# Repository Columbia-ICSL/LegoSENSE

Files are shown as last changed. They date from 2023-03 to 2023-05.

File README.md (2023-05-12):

# LegoSENSE
LegoSENSE makes building and deploying sensing systems as easy and as fast as building legos, for **everyone**. LegoSENSE is a software & hardware framework for rapid sensor deployments.

We have provided detailed documentation (and instructional videos soon), for both users, and developers looking to expand the ecosystem.

## Getting Started

For general users, if your system did not come with the software, please flash our prebuilt Raspberry Pi image to the SD card and plug in the hardware.

To develop or build the system from source, please clone this repository using the following git commands. Make sure to pass the `--recurse-submodules` flag to the clone command.

```bash
git clone --recurse-submodules git@github.com:Columbia-ICSL/LegoSENSE.git
```

`/software` contains the source code for LegoSENSE's software system running on Raspberry Pi.

`/hardware` contains all the design resources for developing hardware modules for LegoSENSE, including instructions, hardware references, and design templates.

## Citation

If your academic work has used LegoSENSE, please cite our paper below.

> Minghui Zhao, Stephen Xia, Jingping Nie, Kaiyuan Hou, Avik Dhupar, and Xiaofan Jiang. 2023. LegoSENSE: An Open and Modular Sensing Platform for Rapidly-Deployable IoT Applications. In International Conference on Internet-of-Things Design and Implementation (IoTDI '23), May 09--12, 2023, San Antonio, TX, USA. ACM, New York, NY, USA 14 Pages. [https://doi.org/10.1145/3576842.3582369](https://doi.org/10.1145/3576842.3582369)

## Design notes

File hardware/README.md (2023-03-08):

# LegoSENSE Development Guide - Hardware
*This document is written for a hardware developer audience. For information on using LegoSENSE, see [Getting Started](../README.md).*

## Getting Started: hardware design steps

### Step 1: Get Sensor to Work on Breadboard

Acquire a sensor evaluation board (breakout board) and make it work with Raspberry Pi. You may consult the sensor manufacturer for example codes and getting started guides. Once you have the sensor's driver code running on Raspberry Pi and are able to acquire data, you are ready for the next step.

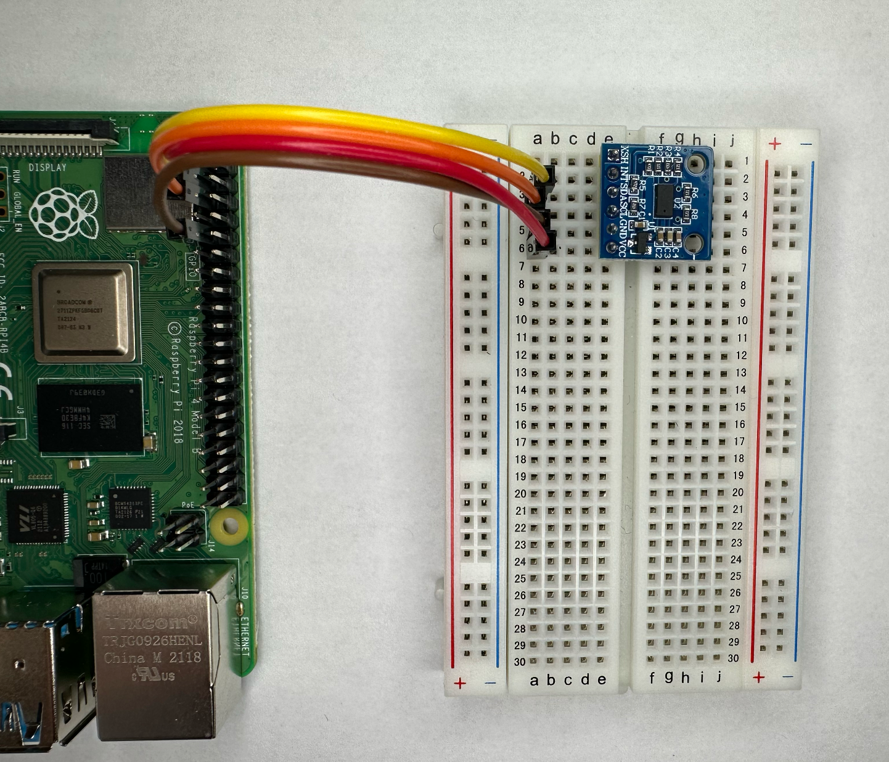
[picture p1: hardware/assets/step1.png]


### Step 2: Switch to Module Development Board

In this step, you will move the sensor circuit to a module-like development board that can be plugged into LegoSENSE's carrier board.

There are three module development boards you can use as shown below. On the top half of the board, the 21-Pin connector is broken out for soldering; on the bottom half of the board, type 1 employs a breadboard-style layout, type 2 employs a protoboard-style layout and type 3 includes the common 1.25mm JST connector and 1.0mm I2C connector (STEMMA QT / Qwiic).

| Development Board Type 1 | Development Board Type 2 | Development Board Type 3 |
| --- | --- | --- |
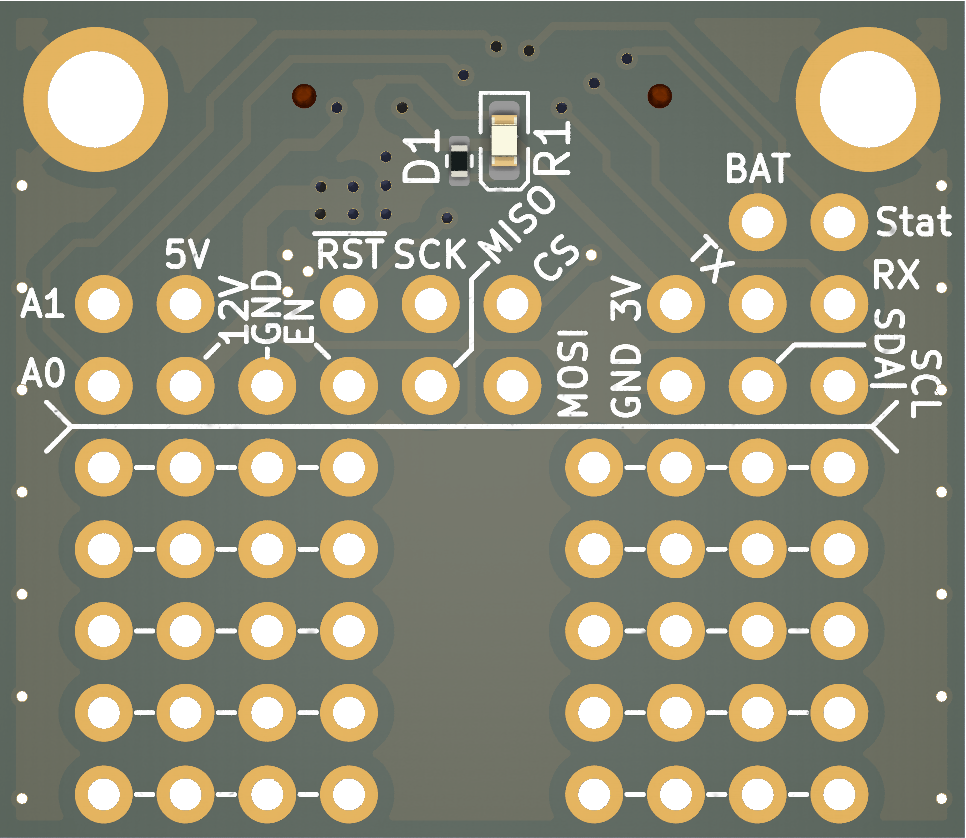
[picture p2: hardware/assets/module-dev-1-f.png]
module-dev-1-f
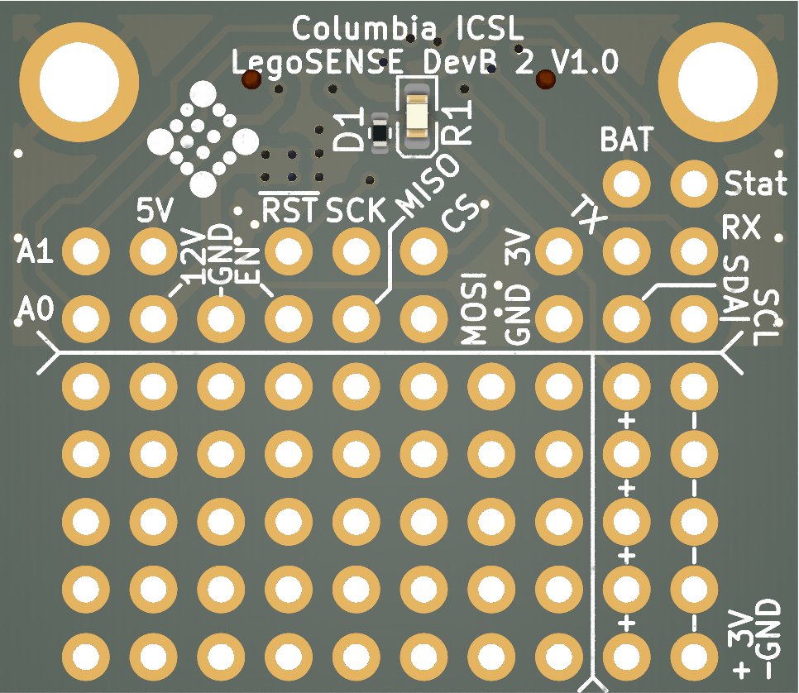
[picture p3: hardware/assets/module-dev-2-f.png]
module-dev-2-f
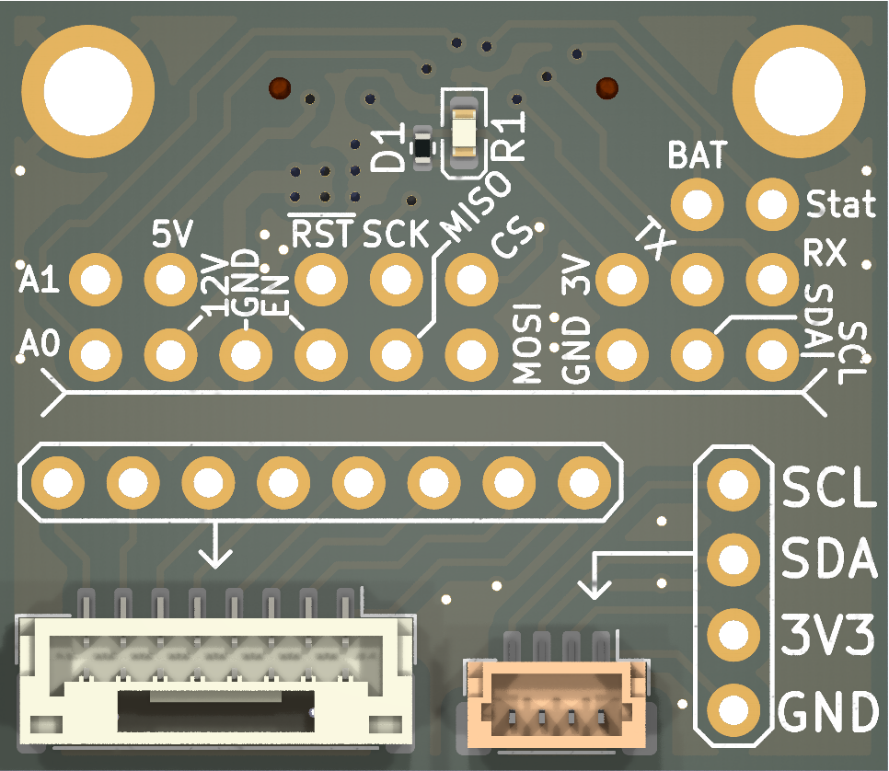
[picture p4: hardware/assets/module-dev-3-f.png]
module-dev-3-f
|  |  |  |
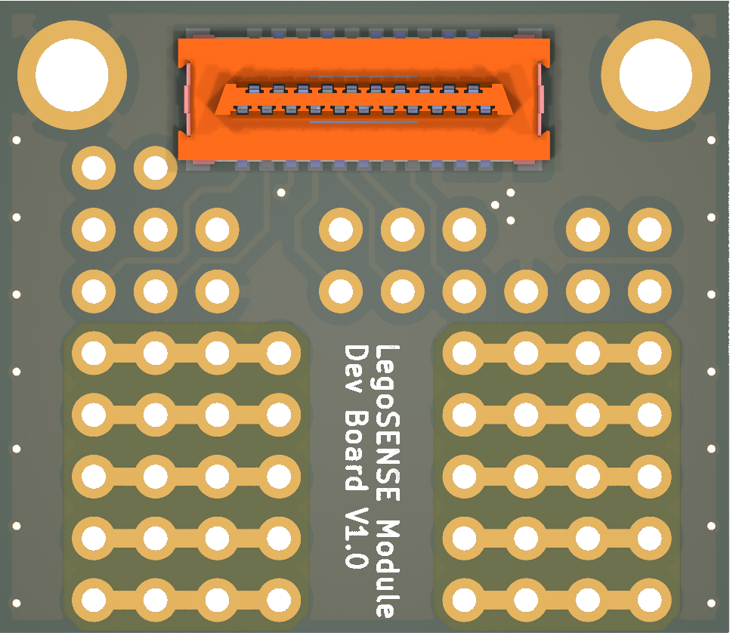
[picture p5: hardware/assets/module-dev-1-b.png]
module-dev-1-b
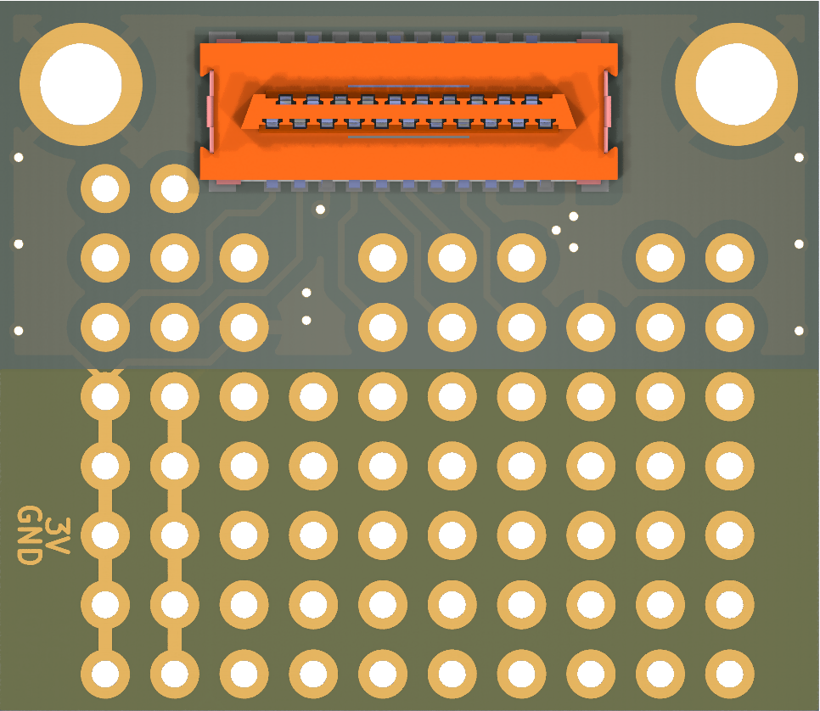
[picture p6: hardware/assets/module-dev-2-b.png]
module-dev-2-b
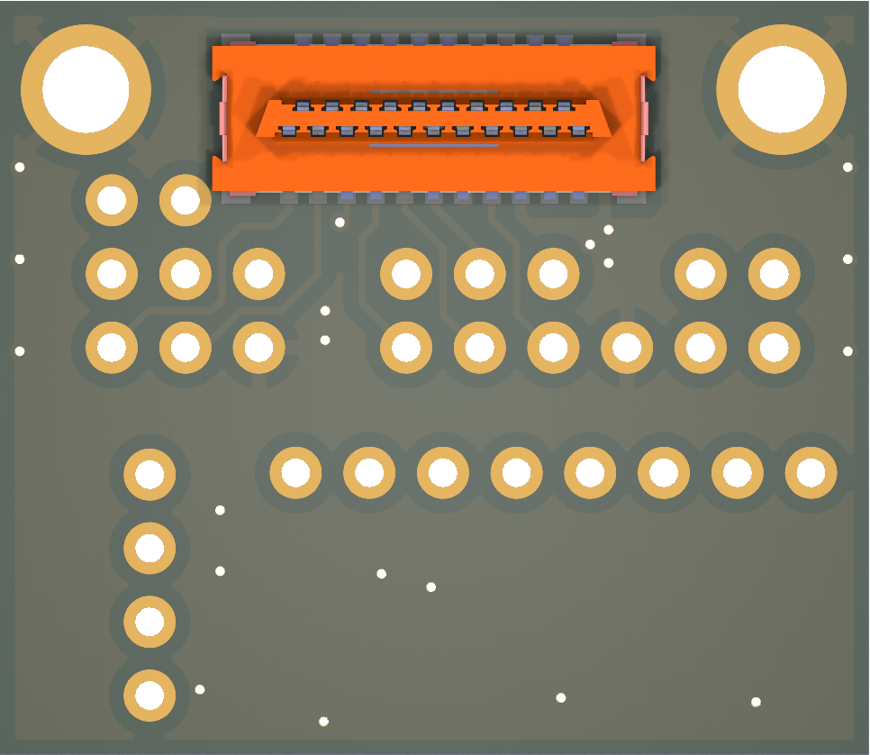
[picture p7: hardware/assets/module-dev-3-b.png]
module-dev-3-b
|  |  |  |

Choose the one that's most convenient for you to work with, and move the circuit from breadboard to the development board and solder it on there.

Plug the evaluation board into carrier board. Depending on which slot you've plugged in, you will need to change the pin definitions in your sensor driver code to match the pin that the specific carrier board module slot uses. You can consult the table under [Carrier Board Bus Layout](#carrier-board-bus-layout).

Once you get the sensor driver code up running, you are ready for the next step.

### Step 3: Port code into LegoSENSE Framework

In this step, we will port the working sensor driver code into LegoSENSE's framework. Follow [Software Development Guide](../software_dev.md) - once you have the sensor driver running from LegoSENSE's software stack and see the sensor data on the dashboard, you are ready for the final step.

### Step 4: Design and Manufacture Module PCB

In this step, we will create the final version of the sensor module PCB. A template sensor module PCB project is provided in `/hardware/sensor-modules/template`.

| Template Sensor Module PCB (front) | Template Sensor Module PCB (back) |
| --- | --- |
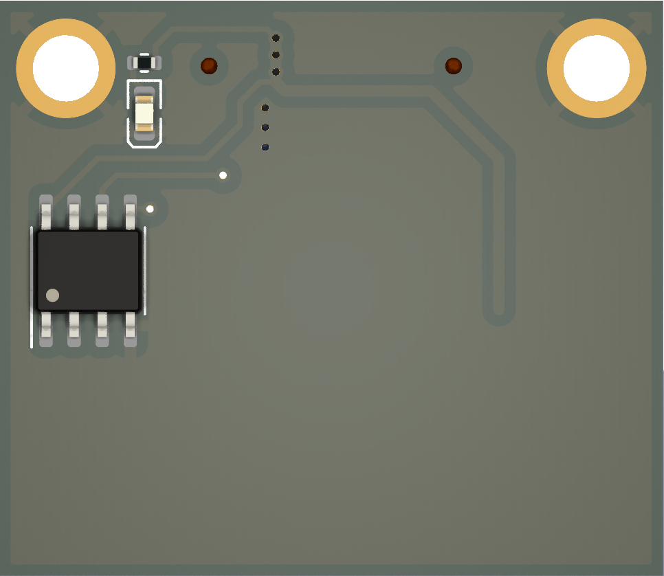
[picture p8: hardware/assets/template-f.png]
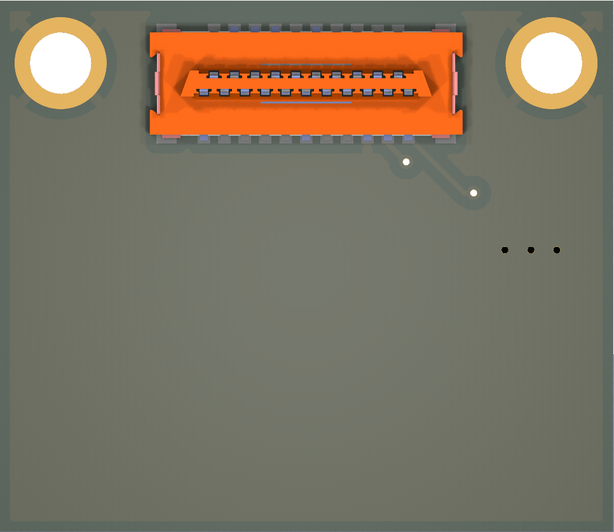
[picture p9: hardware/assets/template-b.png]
|  |  |

1. Duplicating the module template PCB file. This template file is pre-populated with the LegoSENSE standard 21-Pin connector and a EEPROM for auto-recognition of the module. Do not edit this part.
2. Move all the sensor components and peripherials onto the bottom part of the module PCB.
3. Finish the PCB and manufacture it. You could either program the eeprom at manufacturing time and populate it with the ascii string name of the driver, or you can plug in the PCB and use `/software/src/hal/eeprom/write_eep.py` to program the eeprom.

## Project Layout

- `sensor-modules`
  - `template`
  - `<existing_module_names>`
    - `<module_name>.kicad_pro/kicad_sch/kicad_pcb`: KiCad project for the sensor module PCB
    - `jlcpcb`: Folder containing PCB fabrication files. This folder is generated by KiCad plugin [kicad-jlcpcb-tools]( https://github.com/bouni/kicad-jlcpcb-tools).
      - `gerber`: Gerber file for PCB manufacturing
      - `assembly`: Bill of materials (BOM) and parts placement position file for pick-and-place machine (POS)

- `carrier-board`: Carrier board (as a Raspberry Pi shield) PCB design and fabrication files
  - `carrier-board.kicad_pro/kicad_sch/kicad_pcb`: KiCad project for the top-level carrier board PCB
  - `<ADC/eeprom_mux/HeaderToRpi4_overlay1/level_shifter_2ch/sensor_module>.kicad_sch`: Schematics files for submodules in the carrier board PCB project
  - `jlcpcb`: Folder containing PCB fabrication files. This folder is generated by KiCad plugin [kicad-jlcpcb-tools]( https://github.com/bouni/kicad-jlcpcb-tools).
    - `gerber`: Gerber file for PCB manufacturing
    - `assembly`: Bill of materials (BOM) and parts placement position file for pick-and-place machine (POS)
- `module-development-boards`: PCB designs for three different module development boards
- `kicad-library`: Submodule linked to a separate GitHub repository containing the PCB library symbols of the components used in the hardware designs.

### Current List of PCB Design Files

#### Carrier Board PCB

| Carrier Board Front Side | Carrier Board Back Side |
| --- | --- |
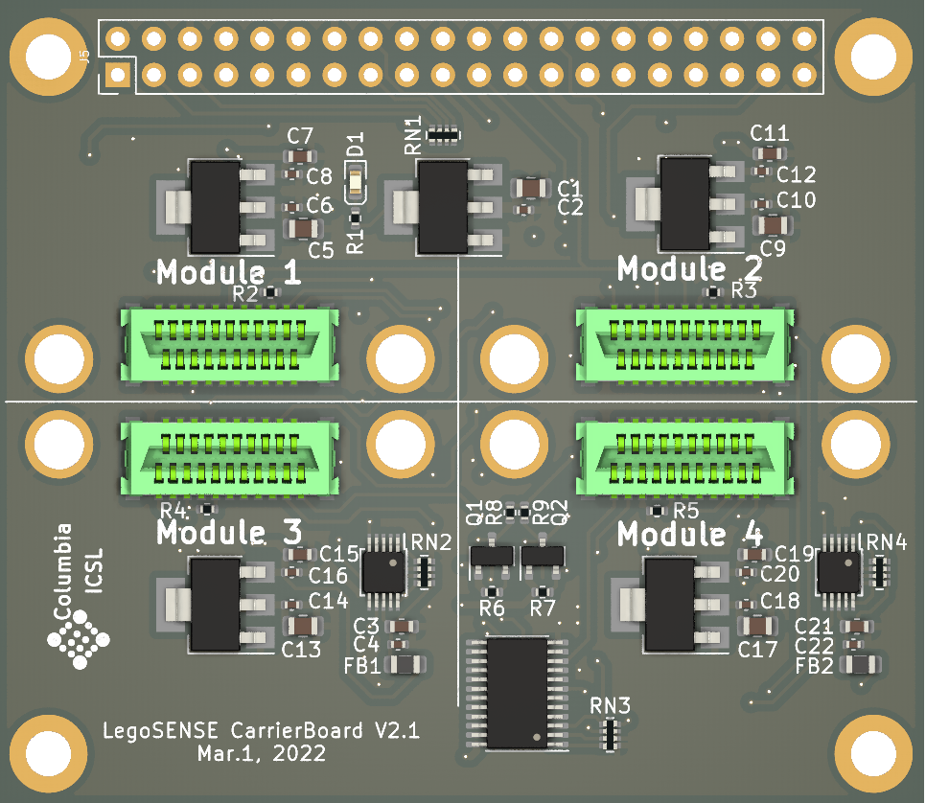
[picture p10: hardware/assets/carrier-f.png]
carrier-f
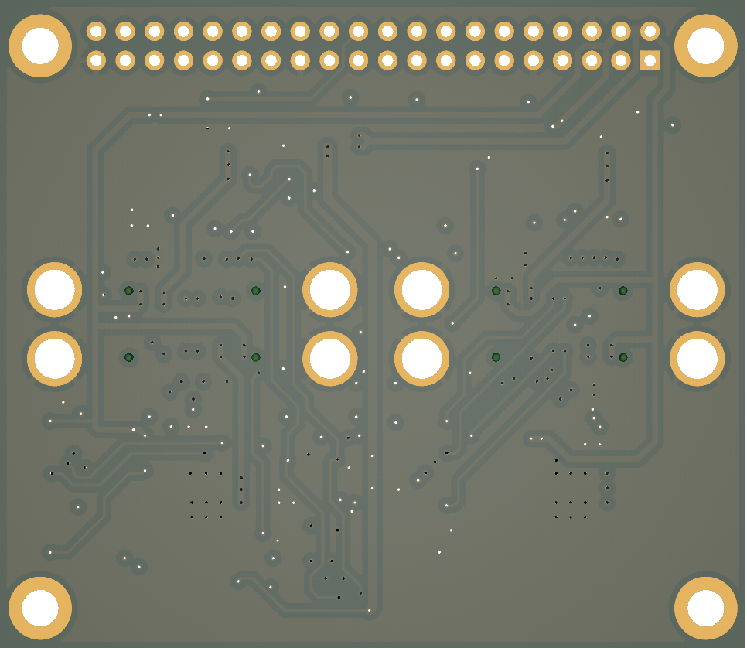
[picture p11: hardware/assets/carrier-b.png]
carrier-b
|  |  |

#### Sensor Modules

| **M1: Temperature, Humidity, Pressure, Wind Speed** | **M2: Ambient Light Color, Light Intensity** | **M3: Proximity, Microphone** | **M4: Motion (IMU)** |
| --- | --- | --- | --- |
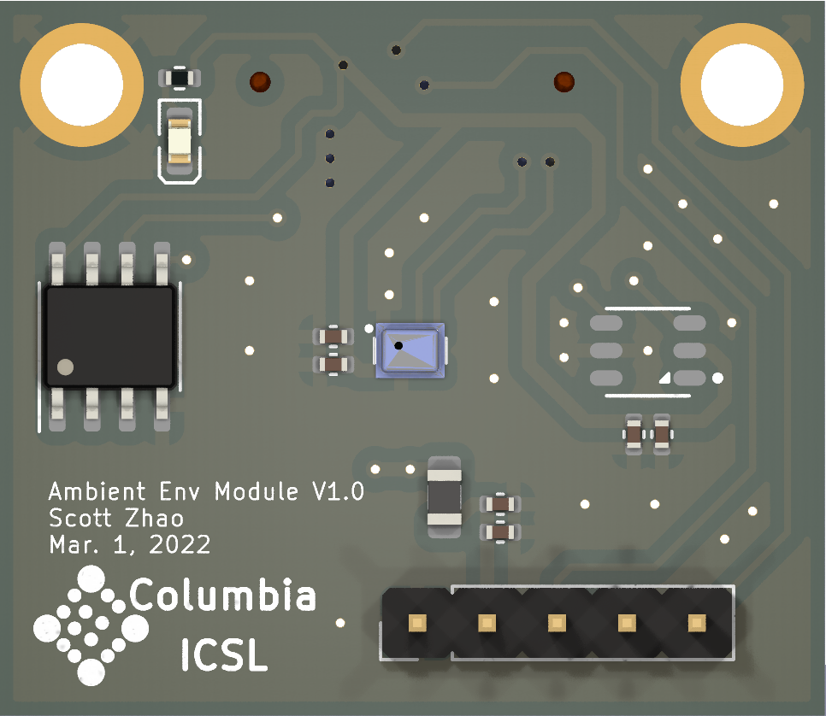
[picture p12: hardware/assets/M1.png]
M1
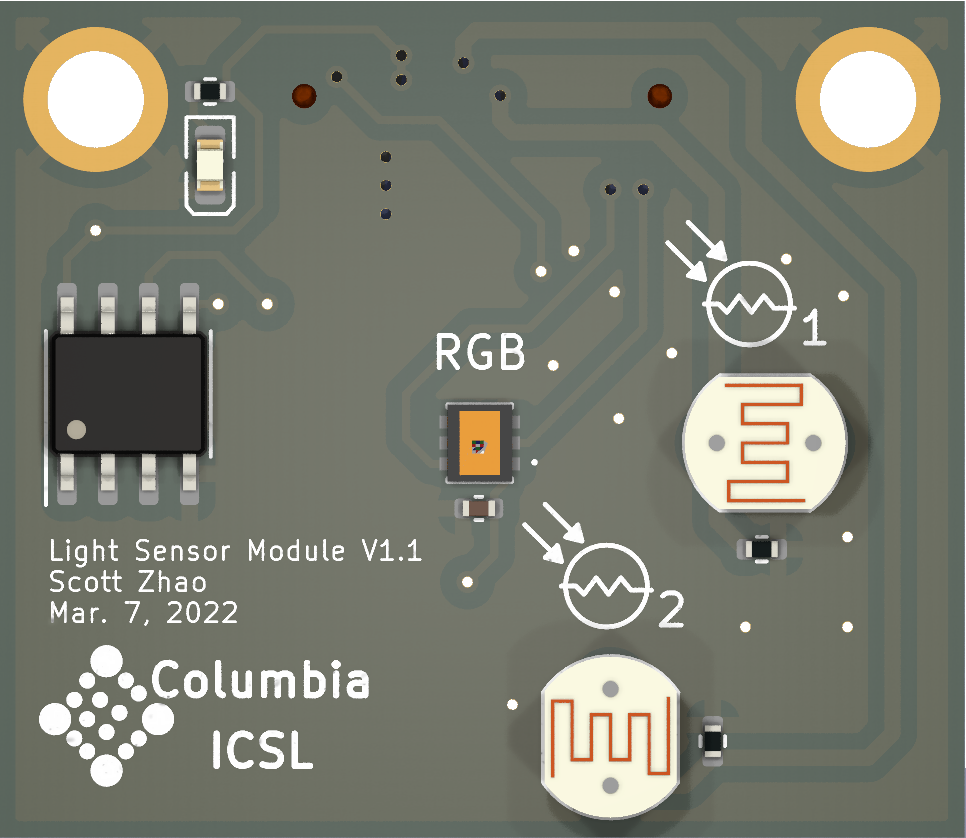
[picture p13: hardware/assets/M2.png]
M2
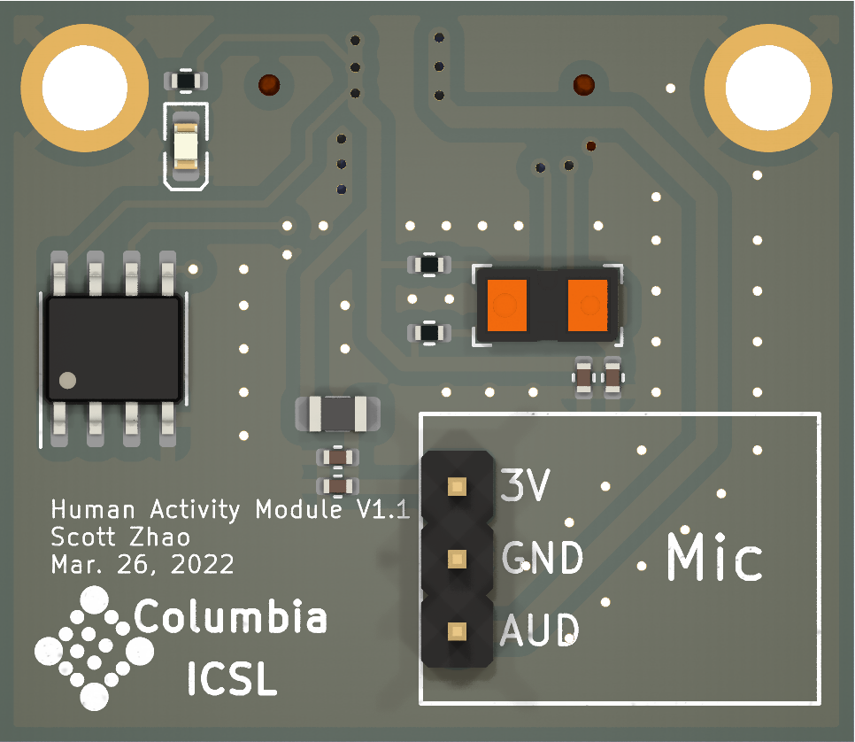
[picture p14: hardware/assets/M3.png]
M3
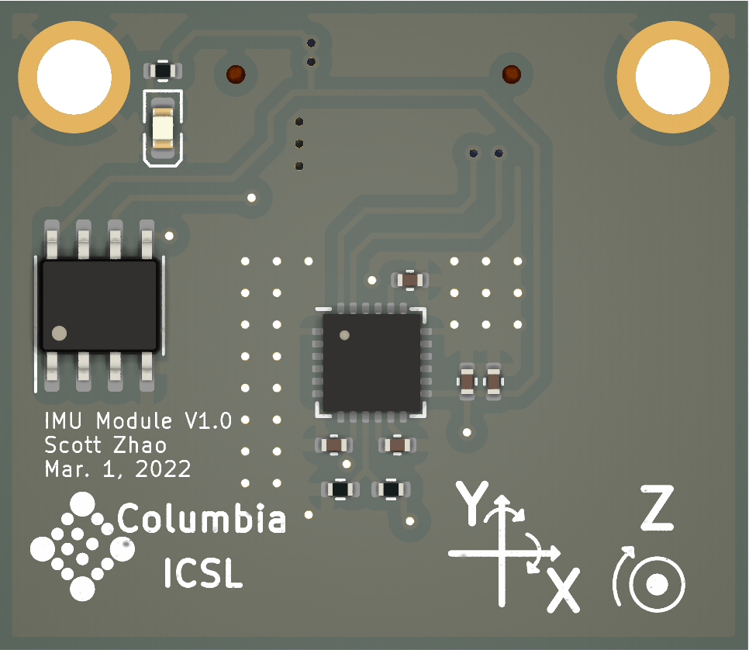
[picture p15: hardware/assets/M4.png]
M4
|  |  |  |  |
| **M5: Thermocouple (Temperature)** | **M6: Particulate Matter (PM1, PM2.5, PM10); Any I2C Sensor with STEMMA QT / Qwiic** | **M7: CO2, Volatile Organic Compound** | **M8: Gas Density (MQ-X Series)** |
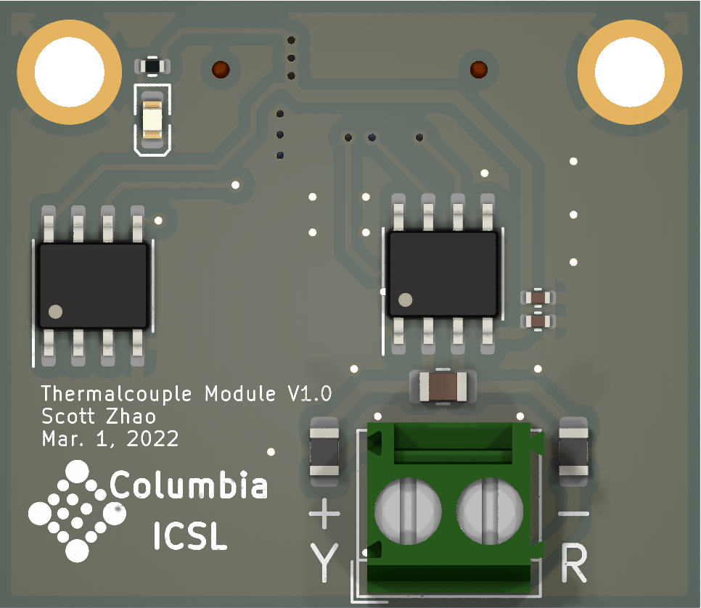
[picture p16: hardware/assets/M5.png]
M5
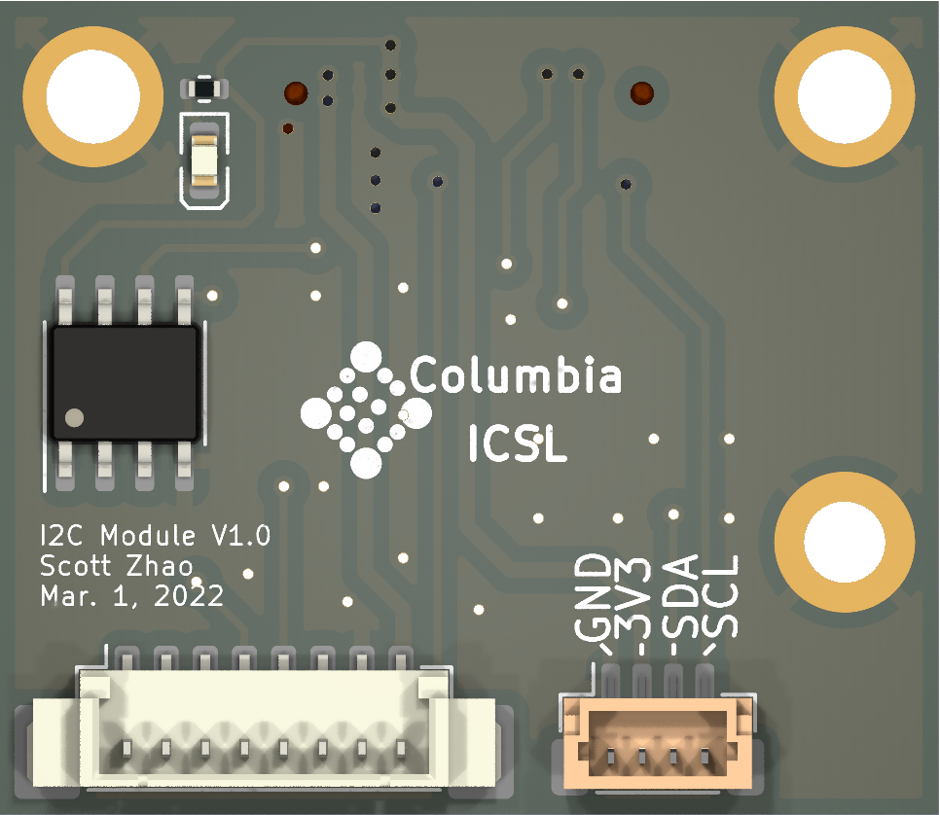
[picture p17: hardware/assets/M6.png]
M6
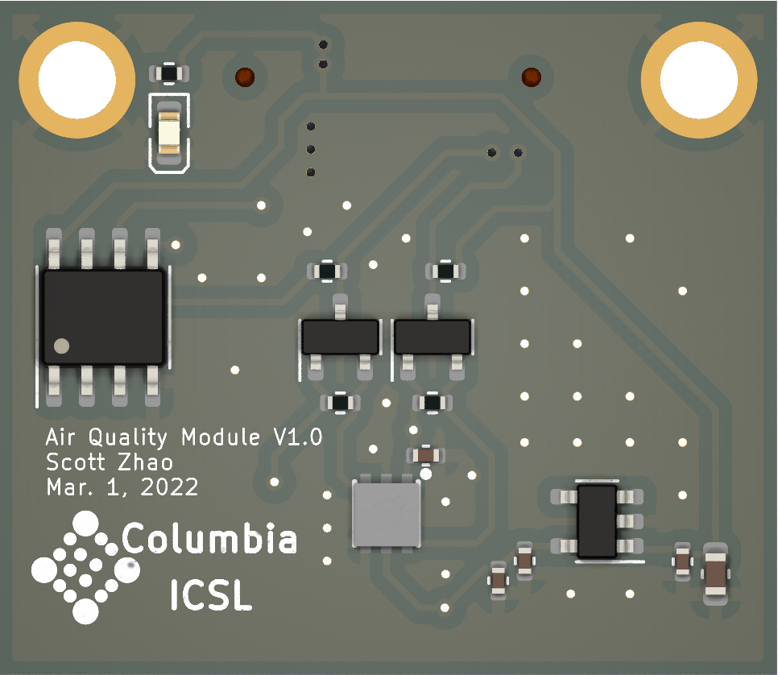
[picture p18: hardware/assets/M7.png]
M7
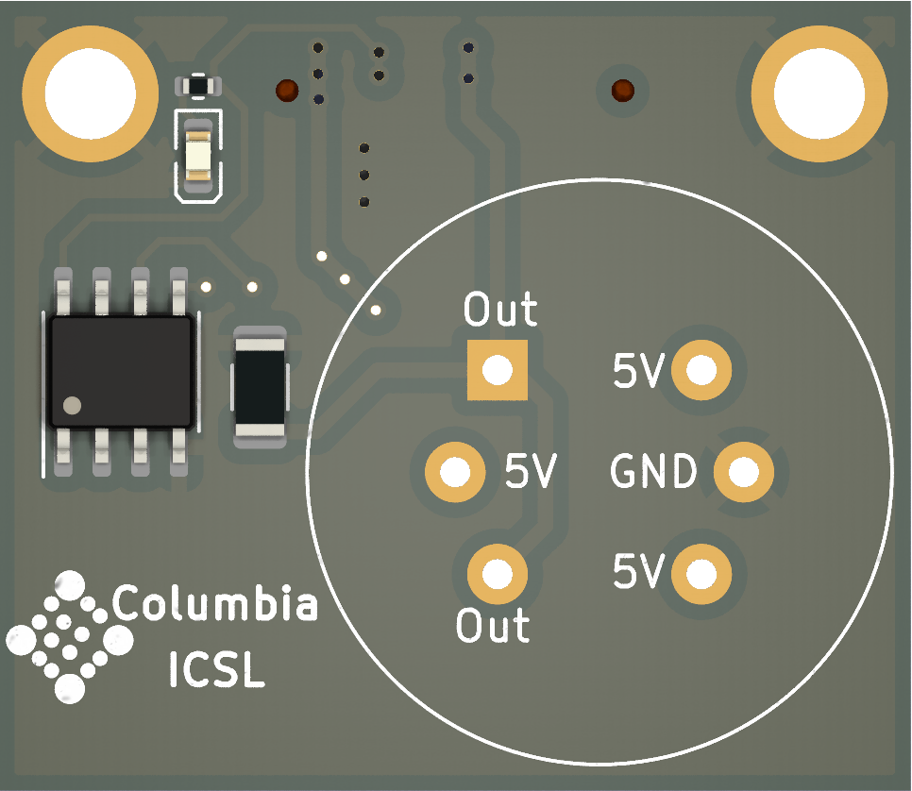
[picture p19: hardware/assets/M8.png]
M8
|  |  |  |  |

## Carrier Board Bus Layout
Note: Raspberry Pi GPIO numbering in this table are BCM (broadcom) pin numbers and is not the physical pin on Raspberry Pi board.

| | I2C | SPI | UART (TX, RX) | ADC | GPIO |
| --- | --- | --- | --- | --- | ---- |
| Module 1 | I2C1 <br/>`/dev/i2c-1` | SPI0, CS0 <br/>`/dev/spidev0.0` | UART1 (14, 15) <br/>`/dev/ttyS0` | ADC1, CH1-2 | 24 |
| Module 2 | I2C1 <br/>`/dev/i2c-1` | SPI0, CS1 <br/>`/dev/spidev0.1` | UART2 (0, 1) <br/>`/dev/ttyAMA1` | ADC1, CH3-4 | 25 |
| Module 3 | I2C6 <br/>`/dev/i2c-6` | SPI1, CS0 <br/>`/dev/spidev1.0` | UART3 (4, 5) <br/>`/dev/ttyAMA2` | ADC2, CH1-2 | 26 |
| Module 4 | I2C6 <br/>`/dev/i2c-6` | SPI1, CS1 <br/>`/dev/spidev1.1` | UART5 (12, 13) <br/>`/dev/ttyAMA3` | ADC2, CH3-4 | 27 |
| ADC1 | I2C1, addr=48 | | | | |
| ADC2 | I2C1, addr=49 | | | | |
| EEPROM MUX | I2C1, addr=70 | | | | |

### Raspberry Pi 4 Device Tree Overlay
```
[spi]
gpio=16,17,18,19,20,21=a4
dtoverlay=spi1-3cs
gpio=7,8,9,10,11=a0
dtoverlay=spi0-2cs

[I2C]
dtoverlay=i2c6

[UART]
enable_uart=1
dtoverlay=uart2
dtoverlay=uart3
dtoverlay=uart5
```

### Raspberry Pi 40-Pin Assignments
| Function | RPi PCB <br/>Pin# (BCM) | RPi PCB <br/>Pin# (BCM) | Function  |
| --- | --- | --- | --- |
| 3V3 | **1** (3V3) | **2** (5V) | 5V |
| I2C1_SDA | **3** (GPIO 2) | **4** (5V) | 5V |
| I2C1_SCL | **5** (GPIO 3) | **6** (GND) | GND |
| UART3_TX | **7** (GPIO 4) | **8** (GPIO 14) | UART0_TX  |
| GND | **9** (GND) | **10** (GPIO 15) | UART0_RX  |
| SPI1_CE1 | **11** (GPIO 17) | **12** (GPIO 18) | SPI1_CE0  |
| GPIO_M4 | **13** (GPIO 27) | **14** (GND) | GND |
| I2C6_SDA | **15** (GPIO 22) | **16** (GPIO 23) | I2C6_SCL  |
| 3V3 | **17** (3V3) | **18** (GPIO 24) | GPIO_M1 |
| SPI0_MOSI  | **19** (GPIO 10) | **20** (GND) | GND |
| SPI0_MISO  | **21** (GPIO 9) | **22** (GPIO 25) | GPIO_M2 |
| SPI0_SCK | **23** (GPIO 11) | **24** (GPIO 8) | SPI0_CE0  |
| GND | **25** (GND) | **26** (GPIO 7) | SPI0_CE1  |
| UART2_TX | **27** (GPIO 0) | **28** (GPIO 1) | UART2_RX  |
| UART3_RX | **29** (GPIO 5) | **30** (GND) | GND |
| *Not Used* | **31** (GPIO 6) | **32** (GPIO 12) | UART5_TX  |
| UART5_RX | **33** (GPIO 13) | **34** (GND) | GND |
| SPI1_MISO  | **35** (GPIO 19) | **36** (GPIO 16) | SPI1_CE2  |
| GPIO_M3 | **37** (GPIO 26) | **38** (GPIO 20) | SPI1_MOSI |
| GND | **39** (GND) | **40** (GPIO 21) | SPI1_SCK  |

## Module Connector
The universal connector used for all modules and carrier boards is a pair of 21 Pin Mezzanine Connectors shown below.

| Adapter Board Side<br/>21 Pin Mezzanine Connector Receipt | 21 Pin Mezzanine Connector Plug <br/>Sensor Module Side |
| --- | --- |
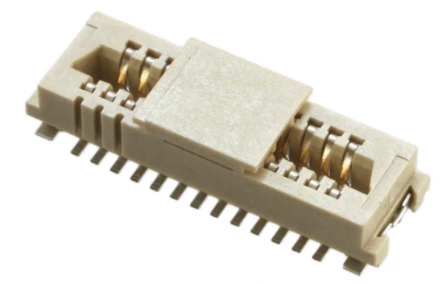
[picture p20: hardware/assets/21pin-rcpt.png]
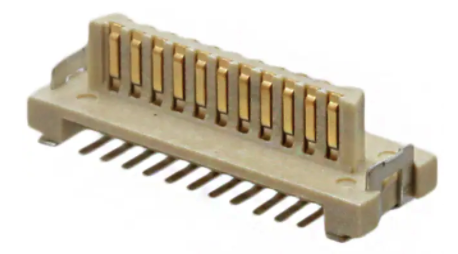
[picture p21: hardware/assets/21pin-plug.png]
|  |  |

The layout for the connector is shown below. It includes pins for the common sensor data communication protocols as follows:

- `SCL, SDA`: I2C
- `CS, MOSI, MISO, SCK`: SPI
- `GPIO`: GPIO digital input / output
- `SCL_E, SDA_E`: I2C for EEPROM (used for module auto-recognition and configuration)
- `RX, TX`: UART
- `ADC0, ADC1`: Two analog input channels

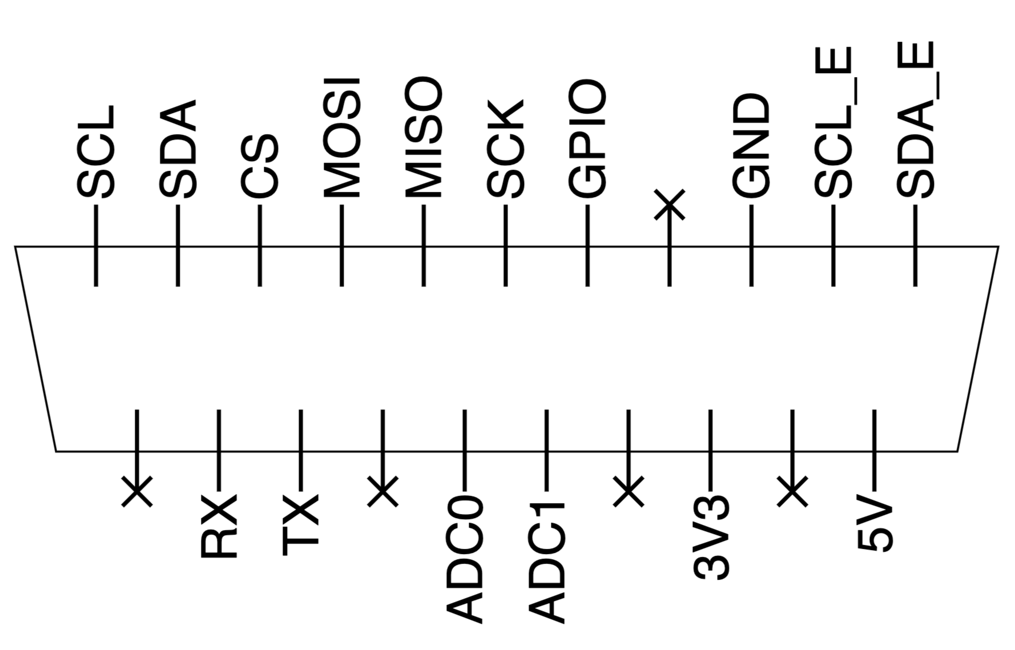
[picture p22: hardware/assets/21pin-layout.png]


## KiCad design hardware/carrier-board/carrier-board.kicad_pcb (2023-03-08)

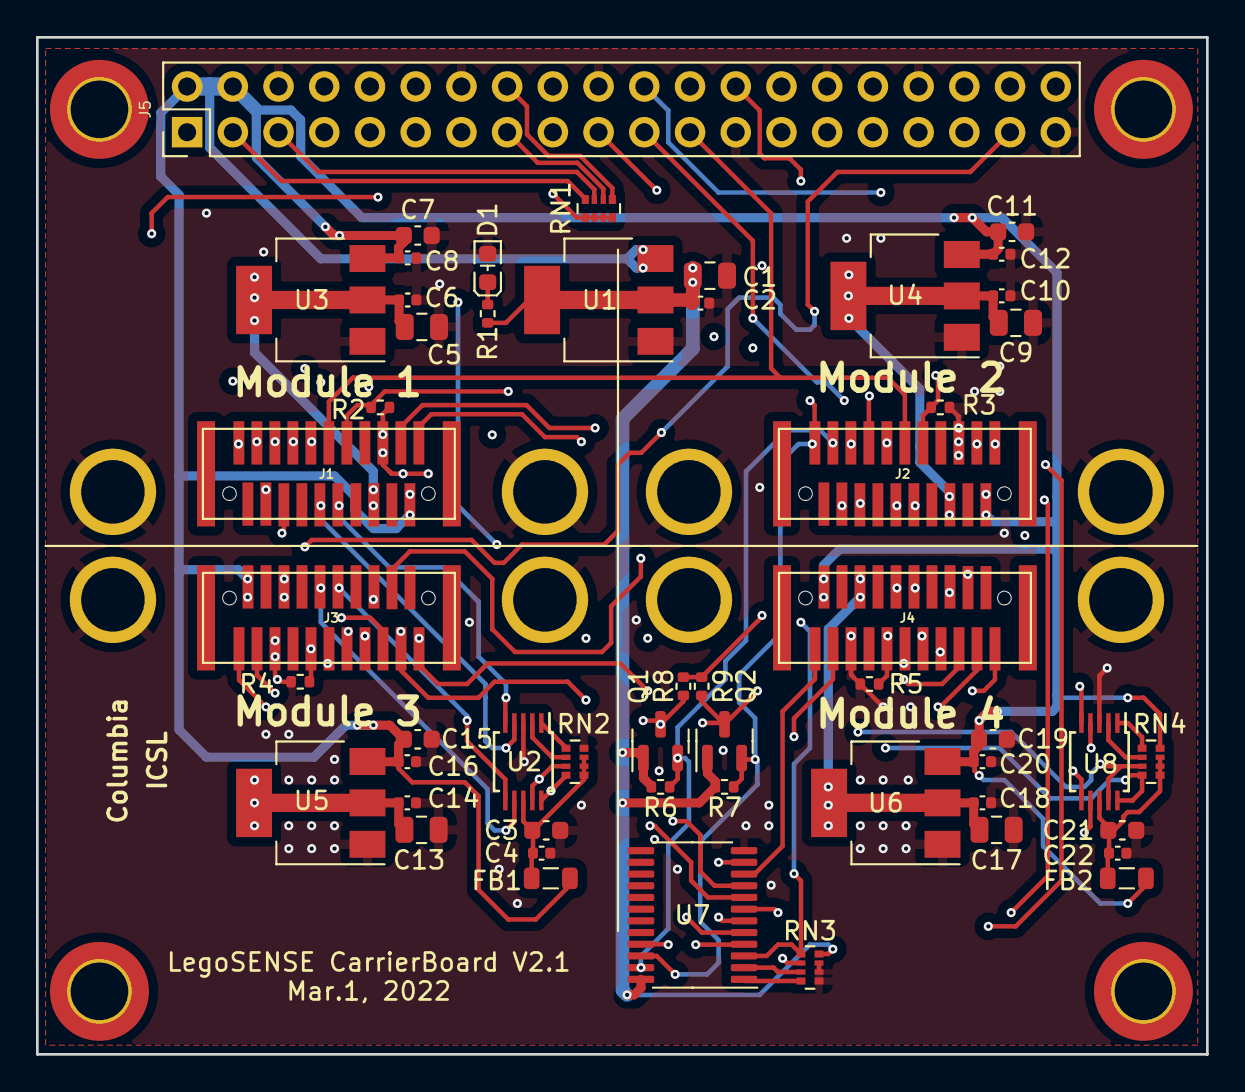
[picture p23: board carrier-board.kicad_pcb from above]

Board: 4 copper layers, 65.0 x 56.5 mm, 66 parts (0 on the bottom side), 63 nets.

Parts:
C1, C5, C9, C13, C17: C_0805_10uF_25V; C_0805_2012Metric
C2, C4, C6, C10, C14, C18, C22: C_0402_1uF_25V; C_0402_1005Metric
C3, C7, C11, C15, C19, C21: C_0603_4.7uF_16V; C_0603_1608Metric
C8, C12, C16, C20: C_0402_0.1uF_16V; C_0402_1005Metric
D1: LED_0603_Red; LED_0603_1608Metric
FB1, FB2: B_0805_600R; L_0805_2012Metric
H1, H2, H3, H4: MountingHole_Pad; MountingHole_3.2mm_M3_ISO14580_Pad_TopBottom
H5, H6, H7, H8, H9, H10, H11, H12: M1502-B-2545-AL; Spacer_M1502-B-2545_AL
J1, J2, J3, J4: Amphenol_91931-31121_recep; Amphenol_91931_31121LF_RCPT
J5: RPI4_Header; PinHeader_2x20_P2.54mm_Vertical
Q1, Q2: NMOS_BSS138; SOT-23
R1, R2, R3, R4, R5, R6, R7, R8, R9: R_0402_10K; R_0402_1005Metric
RN1, RN2, RN3, RN4: RN_0402x4_10K; R_Array_Convex_4x0402
U1, U3, U4, U5, U6: AMS1117-3.3; SOT-223-3_TabPin2
U2, U8: ADC_ADS1115IDGSR; TSSOP-10_3x3mm_P0.5mm
U7: TCA9548APWR; TSSOP-24_4.4x7.8mm_P0.65mm
U9: ICSL_LOGO; icsl_logo

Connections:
+3V3: C1.1, C2.1, Q1.1 (G), Q2.1 (G), R1.1, R6.1, R7.1, RN3.5 (R4_B), U1.2 (VO), U7.24 (VCC)
/3V_RPi: J5.1, J5.17, RN1.5 (R4_B), RN1.6 (R3_B), RN1.7 (R2_B), RN1.8 (R1_B)
/5V_RPi: C7.1, C8.1, C11.1, C12.1, C15.1, C16.1, C19.1, C20.1, FB1.1, FB2.1, J1.21, J2.21, J3.21, J4.21, J5.2, J5.4, R8.1, R9.1, RN4.1 (R1_T), U1.3 (VI), U3.3 (VI), U4.3 (VI), U5.3 (VI), U6.3 (VI)
/ADC1/VCC_ADC: C3.1, C4.1, FB1.2, RN2.2 (R2_T), RN2.3 (R3_T), RN2.4 (R4_T), U2.8 (VDD)
/ADC2/VCC_ADC: C21.1, C22.1, FB2.2, RN4.2 (R2_T), RN4.3 (R3_T), RN4.4 (R4_T), U8.8 (VDD)
/AN1N: J1.17, U2.5 (AIN1)
/AN1P: J1.16, U2.4 (AIN0)
/AN2N: J2.17, U8.5 (AIN1)
/AN2P: J2.16, U8.4 (AIN0)
/AN3N: J3.17, U2.7 (AIN3)
/AN3P: J3.16, U2.6 (AIN2)
/AN4N: J4.17, U8.7 (AIN3)
/AN4P: J4.16, U8.6 (AIN2)
/GPIO6: J5.31, RN3.4 (R4_T), U7.3 (~RESET)
/GPIO24: J1.5, J5.18, R2.2
/GPIO25: J2.5, J5.22, R3.2
/GPIO26: J3.5, J5.37, R4.2
/GPIO27: J4.5, J5.13, R5.2
/RXD0: J1.13, J5.10
/RXD2: J2.13, J5.28
/RXD3: J3.13, J5.29
/RXD5: J4.13, J5.33
/SCL1: J1.11, J2.11, J5.5, Q2.2 (S), R7.2, RN1.2 (R2_T), U7.22 (SCL)
/SCL1_5V: Q2.3 (D), R9.2, RN2.5 (R4_B), RN4.5 (R4_B), U2.10 (SCL), U8.10 (SCL)
/SCL6: J3.11, J4.11, J5.16, RN1.4 (R4_T)
/SCL_EEPROM1: J1.2, U7.5 (SC0)
/SCL_EEPROM2: J2.2, U7.7 (SC1)
/SCL_EEPROM3: J3.2, U7.9 (SC2)
/SCL_EEPROM4: J4.2, U7.11 (SC3)
/SDA1: J1.10, J2.10, J5.3, Q1.2 (S), R6.2, RN1.1 (R1_T), U7.23 (SDA)
/SDA1_5V: Q1.3 (D), R8.2, RN2.6 (R3_B), RN4.6 (R3_B), U2.9 (SDA), U8.9 (SDA)
/SDA6: J3.10, J4.10, J5.15, RN1.3 (R3_T)
/SDA_EEPROM1: J1.1, U7.4 (SD0)
/SDA_EEPROM2: J2.1, U7.6 (SD1)
/SDA_EEPROM3: J3.1, U7.8 (SD2)
/SDA_EEPROM4: J4.1, U7.10 (SD3)
/SPI0CE0: J1.9, J5.24
/SPI0CE1: J2.9, J5.26
/SPI0MISO: J1.7, J2.7, J5.21
/SPI0MOSI: J1.8, J2.8, J5.19
/SPI0SCLK: J1.6, J2.6, J5.23
/SPI1CE0: J3.9, J5.12
/SPI1CE1: J4.9, J5.11
/SPI1MISO: J3.7, J4.7, J5.35
/SPI1MOSI: J3.8, J4.8, J5.38
/SPI1SCLK: J3.6, J4.6, J5.40
/TXD0: J1.14, J5.8
/TXD2: J2.14, J5.27
/TXD3: J3.14, J5.7
/TXD5: J4.14, J5.32
/module1/3.3V: C5.1, C6.1, J1.19, U3.2 (VO)
/module2/3.3V: C9.1, C10.1, J2.19, U4.2 (VO)
/module3/3.3V: C13.1, C14.1, J3.19, U5.2 (VO)
/module4/3.3V: C17.1, C18.1, J4.19, U6.2 (VO)
GND: C1.2, C2.2, C3.2, C4.2, C5.2, C6.2, C7.2, C8.2, C9.2, C10.2, C11.2, C12.2, C13.2, C14.2, C15.2, C16.2, C17.2, C18.2, C19.2, C20.2, C21.2, C22.2, D1.1 (K), H5.1, H6.1, H7.1, H8.1, H9.1, H10.1, H11.1, H12.1, J1.3, J2.3, J3.3, J4.3, J5.6, J5.9, J5.14, J5.20, J5.25, J5.30, J5.34, J5.39, R2.1, R3.1, R4.1, R5.1, RN2.1 (R1_T), RN3.6 (R3_B), RN3.7 (R2_B), RN3.8 (R1_B), U1.1 (GND), U2.3 (GND), U3.1 (GND), U4.1 (GND), U5.1 (GND), U6.1 (GND), U7.12 (GND), U8.3 (GND)
unnamed: D1.2 (A), R1.2
unnamed: RN2.7 (R2_B), U2.2 (ALERT/RDY)
unnamed: RN2.8 (R1_B), U2.1 (ADDR)
unnamed: RN3.1 (R1_T), U7.1 (A0)
unnamed: RN3.2 (R2_T), U7.2 (A1)
unnamed: RN3.3 (R3_T), U7.21 (A2)
unnamed: RN4.7 (R2_B), U8.2 (ALERT/RDY)
unnamed: RN4.8 (R1_B), U8.1 (ADDR)

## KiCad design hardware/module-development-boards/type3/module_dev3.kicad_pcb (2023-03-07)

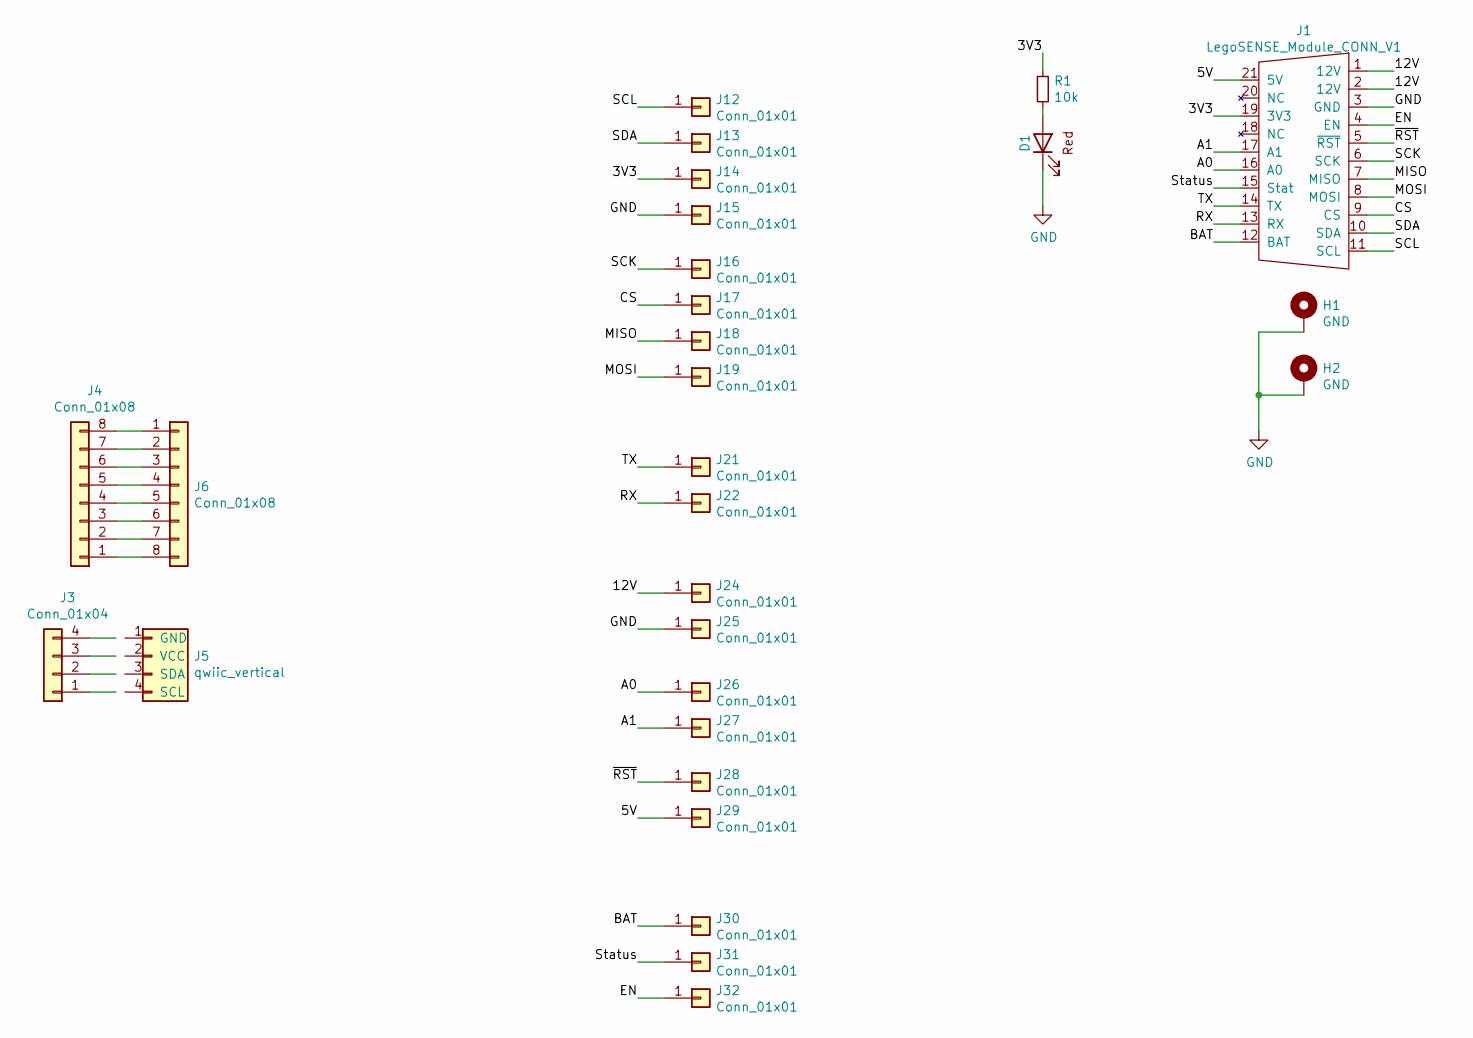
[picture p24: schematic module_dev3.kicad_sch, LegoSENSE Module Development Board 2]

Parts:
D1: LED_0603_Red; LED_0603_1608Metric; MFR Part# KT-0603R; LCSC C2286
H1, H2: GND; M1502-B-2545-AL-TOP
J1: LegoSENSE_Module_CONN_V1; Amphenol_91911-31321LF_PLUG
J3: Conn_01x04; PinHeader_1x04_2.54mm_NoSilk
J4: Conn_01x08; PinHeader_1x08_2.54mm_NoSilk
J5: qwiic_vertical; JST_SH_1x04_1.00mm_Vertical
J6: Conn_01x08; JST_GH_BM08B-GHS-TBT_1x08-1MP_P1.25mm_Vertical
J12, J13, J14, J15, J16, J17, J18, J19, J21, J22, J24, J25, J26, J27, J28, J29, J30, J31, J32: Conn_01x01; PinHeader_1x01_NoSilk
R1: 10k; R_0402_1005Metric; LCSC C25744

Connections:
/3V3: J1.19 (3V3), J14.1, R1.1
/5V: J1.21 (5V), J29.1
/12V: J1.1 (12V), J1.2 (12V), J24.1
/A0: J1.16 (A0), J26.1
/A1: J1.17 (A1), J27.1
/BAT: J1.12 (BAT), J30.1
/CS: J1.9 (CS), J17.1
/EN: J1.4 (EN), J32.1
/MISO: J1.7 (MISO), J18.1
/MOSI: J1.8 (MOSI), J19.1
/RX: J1.13 (RX), J22.1
/SCK: J1.6 (SCK), J16.1
/SCL: J1.11 (SCL), J12.1
/SDA: J1.10 (SDA), J13.1
/Status: J1.15 (Stat), J31.1
/TX: J1.14 (TX), J21.1
/~RST: J1.5 (~RST), J28.1
GND: D1.1 (K), H1.1, H2.1, J1.3 (GND), J15.1, J25.1
unnamed: J3.1, J5.4 (SCL)
unnamed: J3.2, J5.3 (SDA)
unnamed: J3.3, J5.2 (VCC)
unnamed: J3.4, J5.1 (GND)
unnamed: J4.1, J6.8
unnamed: J4.2, J6.7
unnamed: J4.3, J6.6
unnamed: J4.4, J6.5
unnamed: J4.5, J6.4
unnamed: J4.6, J6.3
unnamed: J4.7, J6.2
unnamed: J4.8, J6.1

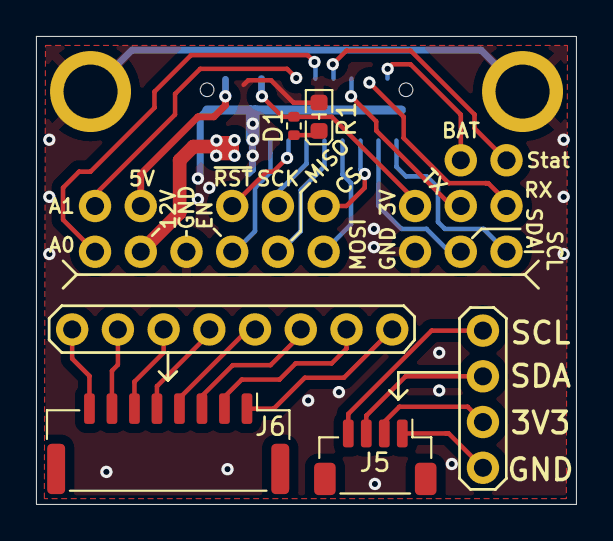
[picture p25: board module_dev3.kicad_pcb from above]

Board: 2 copper layers, 30.0 x 26.0 mm, 28 parts (1 on the bottom side), 30 nets.

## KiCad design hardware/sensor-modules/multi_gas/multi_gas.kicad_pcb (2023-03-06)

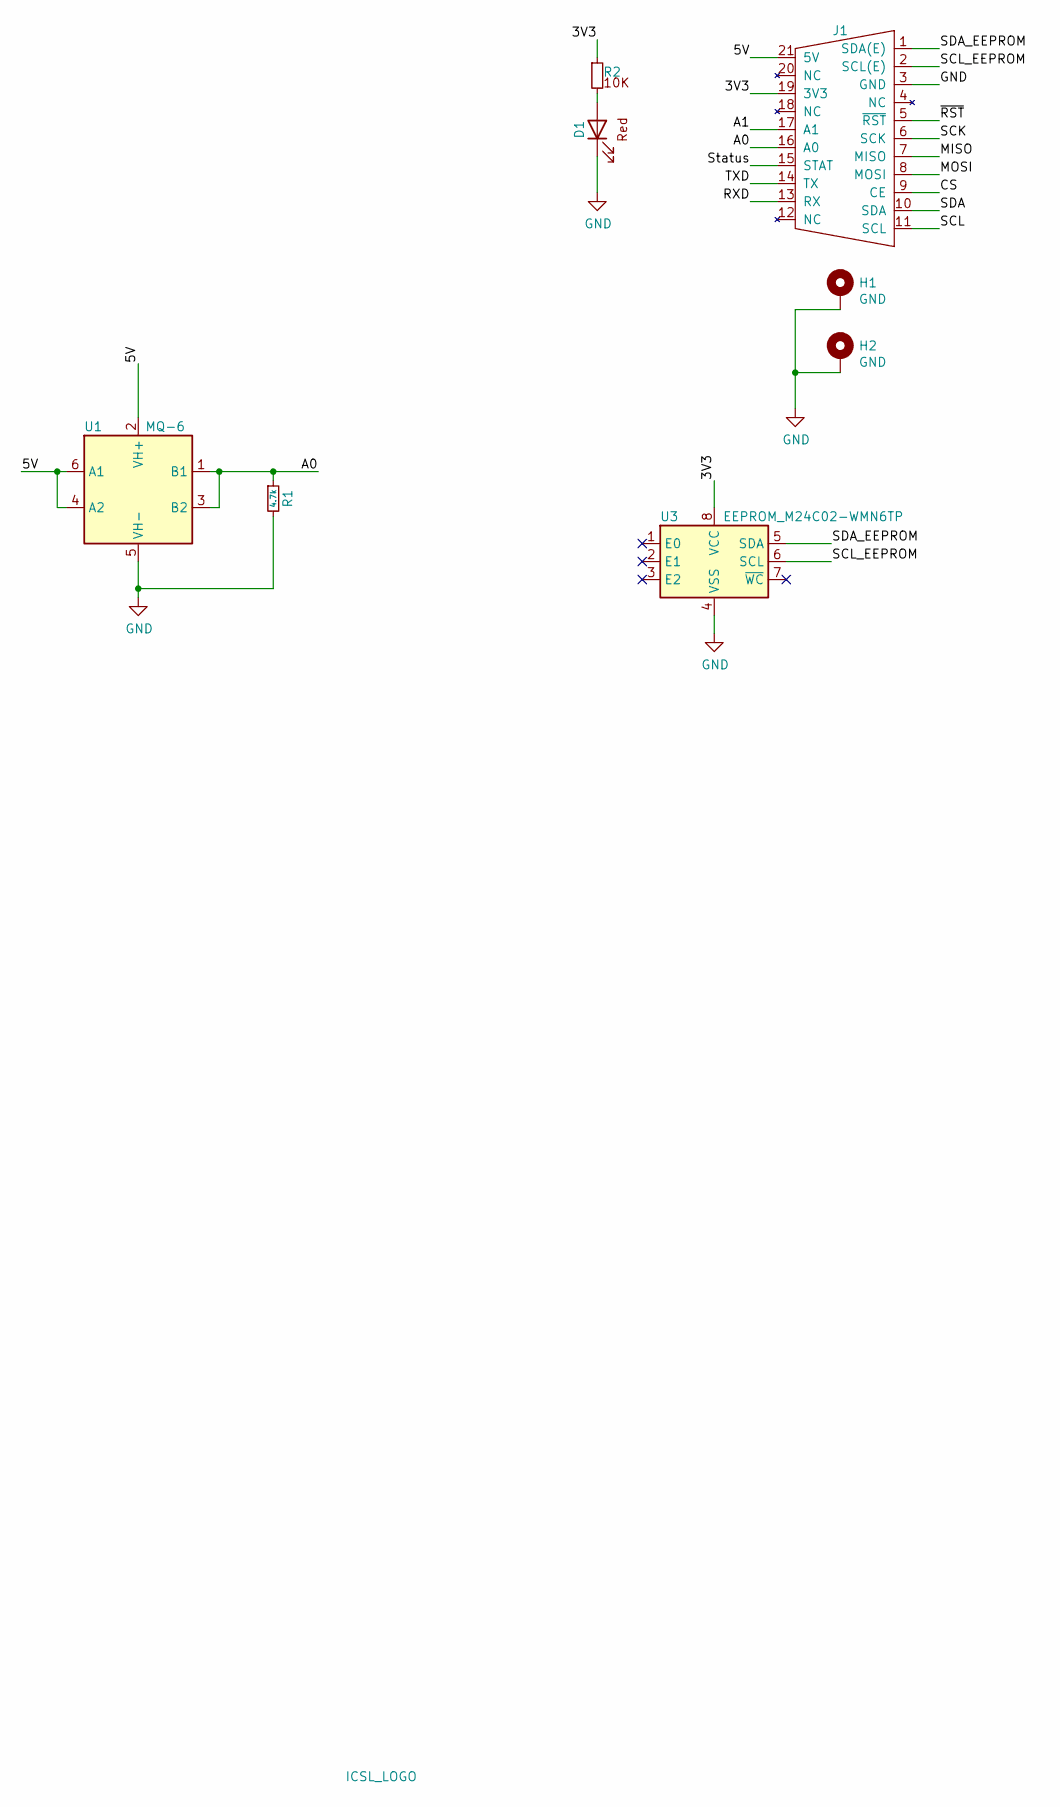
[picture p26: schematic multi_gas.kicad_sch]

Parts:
D1: LED_0603_Red; LED_0603_1608Metric; MFR Part# KT-0603R; LCSC C2286
H1, H2: GND; M1502-B-2545-AL-TOP
J1: Amphenol_91911-31321_plug; Amphenol_91911-31321LF_PLUG; LCSC C9900009023
R1: 4.7k; R_1206_3216Metric; LCSC C17936
R2: R_0402_10K; R_0402_1005Metric; MFR Part# 0402WGF1002TCE; LCSC C25744
U1: MQ-6
U2: ICSL_LOGO; icsl_logo
U3: EEPROM_M24C02-WMN6TP; SOIC-8_3.9x4.9mm_P1.27mm; MFR Part# M24C02-WMN6TP; LCSC C7562

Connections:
/3V3: J1.19 (3V3), R2.1, U3.8 (VCC)
/5V: J1.21 (5V), U1.2 (VH+), U1.4 (A2), U1.6 (A1)
/A0: J1.16 (A0), R1.1, U1.1 (B1), U1.3 (B2)
/A1: J1.17 (A1)
/CS: J1.9 (CE)
/MISO: J1.7 (MISO)
/MOSI: J1.8 (MOSI)
/RXD: J1.13 (RX)
/SCK: J1.6 (SCK)
/SCL: J1.11 (SCL)
/SCL_EEPROM: J1.2 (SCL(E)), U3.6 (SCL)
/SDA: J1.10 (SDA)
/SDA_EEPROM: J1.1 (SDA(E)), U3.5 (SDA)
/Status: J1.15 (STAT)
/TXD: J1.14 (TX)
/~RST: J1.5 (~RST)
GND: D1.1 (K), H1.1, H2.1, J1.3 (GND), R1.2, U1.5 (VH-), U3.4 (VSS)
unnamed: D1.2 (A), R2.2

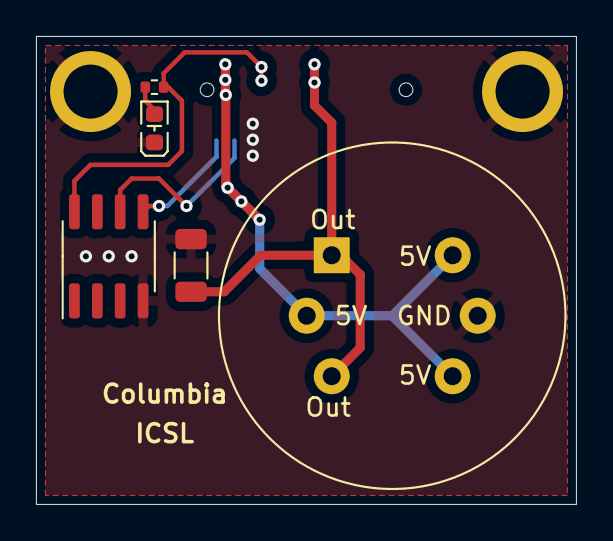
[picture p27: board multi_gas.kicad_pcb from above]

Board: 4 copper layers, 30.0 x 26.0 mm, 9 parts (1 on the bottom side), 7 nets.

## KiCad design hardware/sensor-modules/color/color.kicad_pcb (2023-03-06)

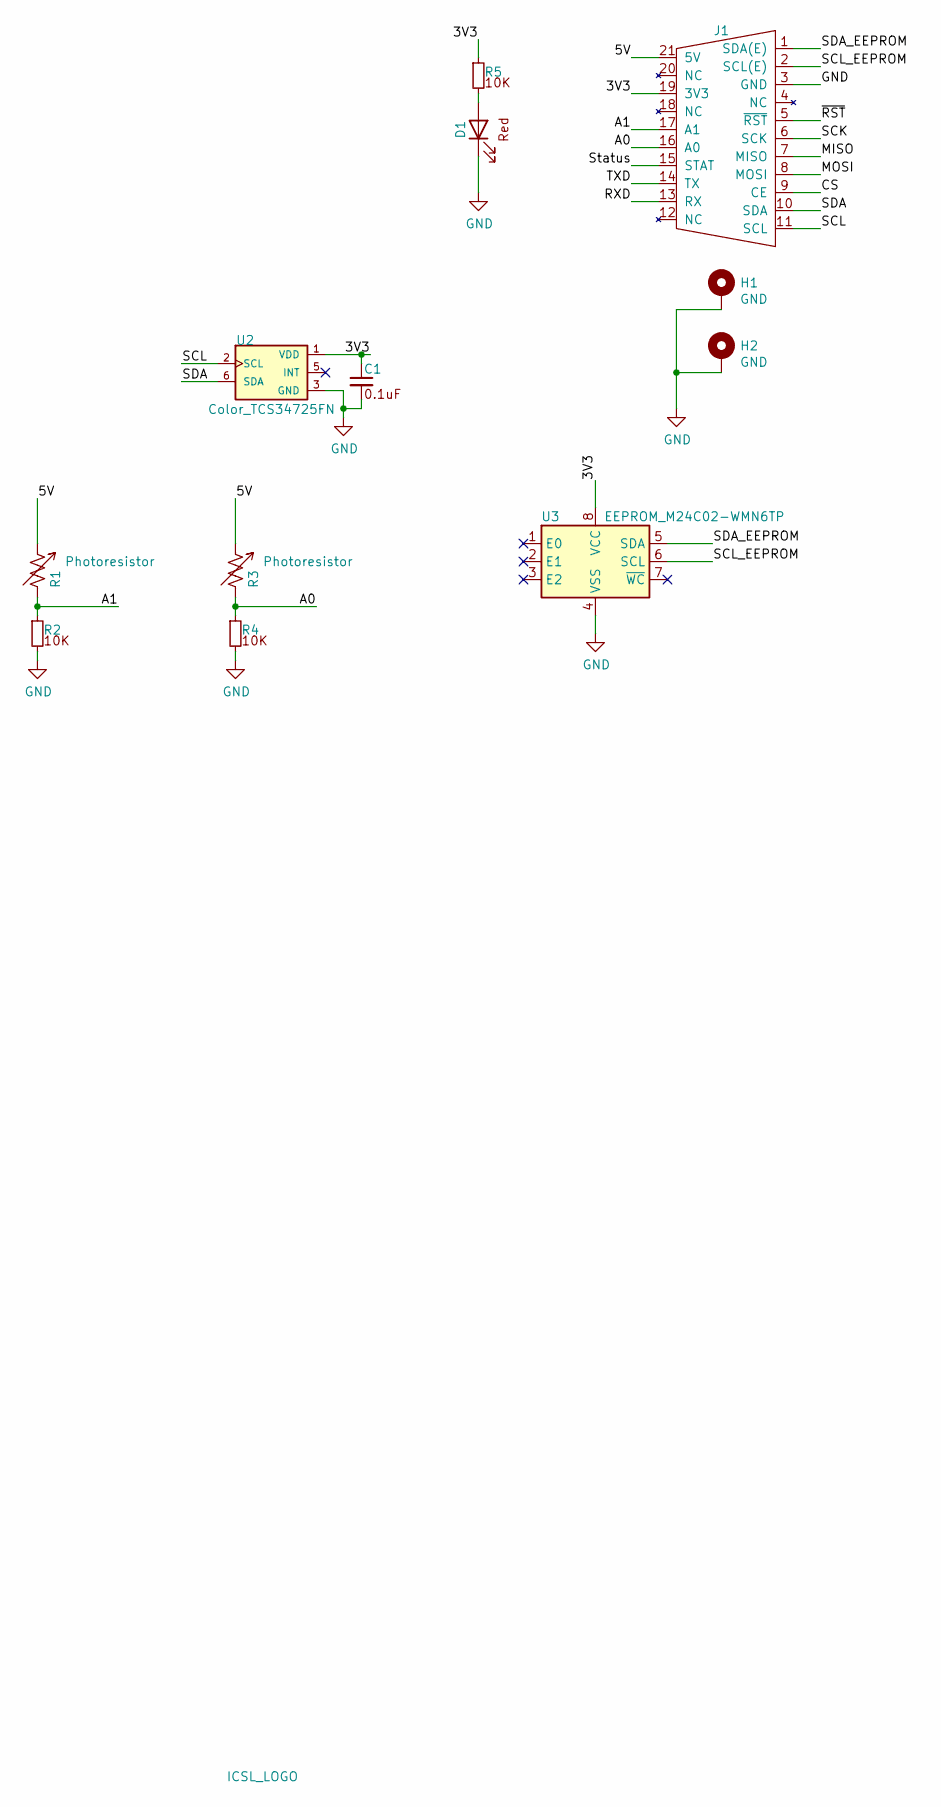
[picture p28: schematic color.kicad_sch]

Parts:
C1: C_0402_0.1uF_16V; C_0402_1005Metric; MFR Part# CL05B104KO5NNNC; LCSC C1525
D1: LED_0603_Red; LED_0603_1608Metric; MFR Part# KT-0603R; LCSC C2286
H1, H2: GND; M1502-B-2545-AL-TOP
J1: Amphenol_91911-31321_plug; Amphenol_91911-31321LF_PLUG; LCSC C9900009023
R1, R3: Photoresistor; R_LDR_5.0x4.1mm_P3mm_Vertical
R2, R4, R5: R_0402_10K; R_0402_1005Metric; MFR Part# 0402WGF1002TCE; LCSC C25744
U1: ICSL_LOGO; icsl_logo
U2: Color_TCS34725FN; TCS34725FN; MFR Part# TCS34725FN; LCSC C2649487
U3: EEPROM_M24C02-WMN6TP; SOIC-8_3.9x4.9mm_P1.27mm; MFR Part# M24C02-WMN6TP; LCSC C7562

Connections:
/3V3: C1.1, J1.19 (3V3), R5.1, U2.1 (VDD), U3.8 (VCC)
/5V: J1.21 (5V), R1.1, R3.1
/A0: J1.16 (A0), R3.2, R4.1
/A1: J1.17 (A1), R1.2, R2.1
/CS: J1.9 (CE)
/MISO: J1.7 (MISO)
/MOSI: J1.8 (MOSI)
/RXD: J1.13 (RX)
/SCK: J1.6 (SCK)
/SCL: J1.11 (SCL), U2.2 (SCL)
/SCL_EEPROM: J1.2 (SCL(E)), U3.6 (SCL)
/SDA: J1.10 (SDA), U2.6 (SDA)
/SDA_EEPROM: J1.1 (SDA(E)), U3.5 (SDA)
/Status: J1.15 (STAT)
/TXD: J1.14 (TX)
/~RST: J1.5 (~RST)
GND: C1.2, D1.1 (K), H1.1, H2.1, J1.3 (GND), R2.2, R4.2, U2.3 (GND), U3.4 (VSS)
unnamed: D1.2 (A), R5.2

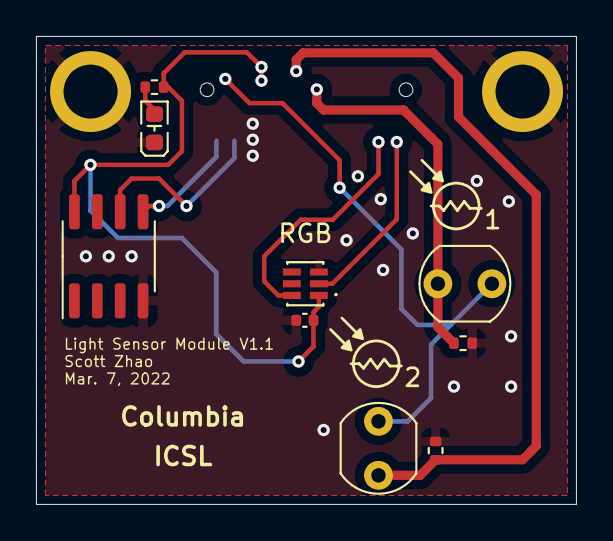
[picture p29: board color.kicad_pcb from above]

Board: 4 copper layers, 30.0 x 26.0 mm, 13 parts (1 on the bottom side), 10 nets.

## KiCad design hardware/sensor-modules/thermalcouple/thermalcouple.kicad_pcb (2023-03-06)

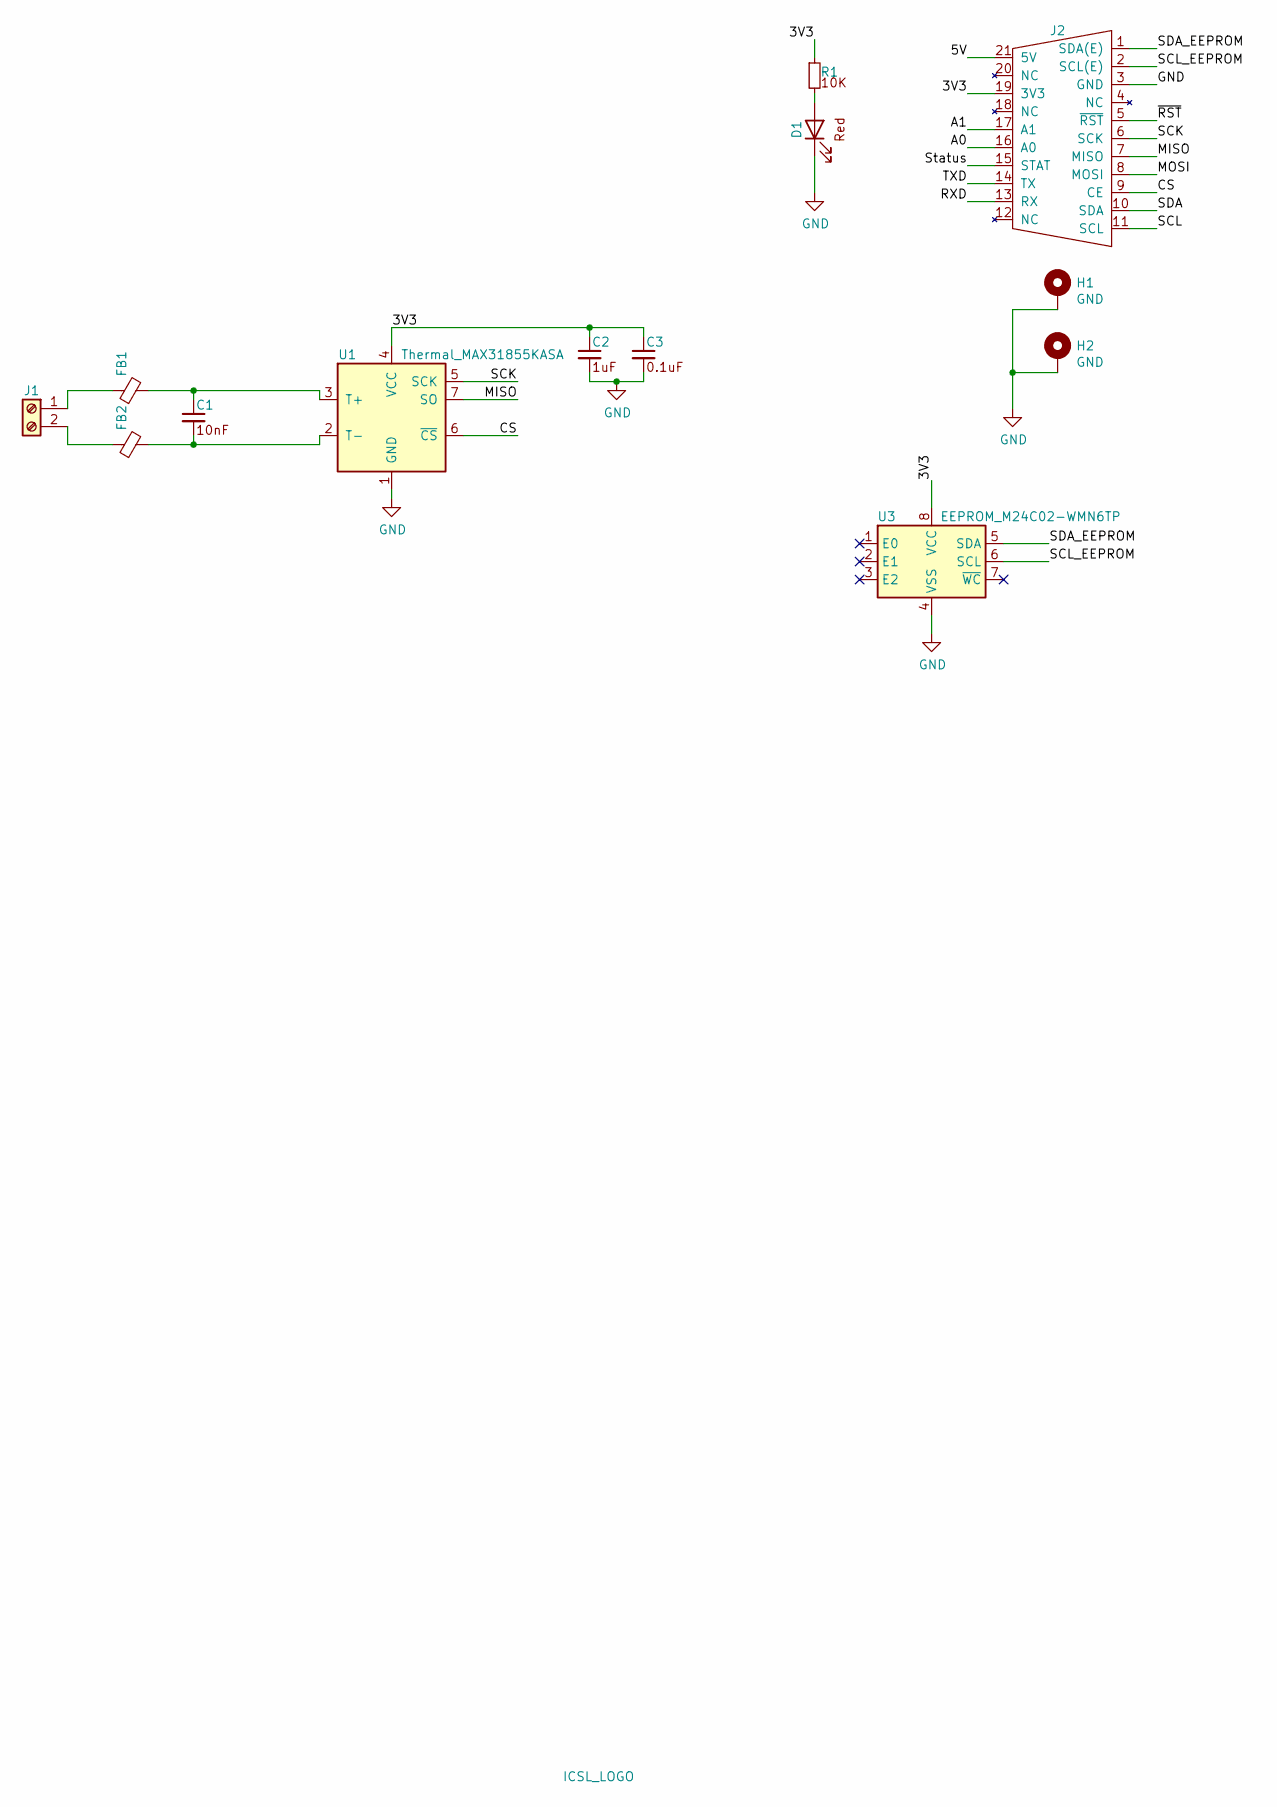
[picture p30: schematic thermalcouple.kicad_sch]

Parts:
C1: C_0805_10nF_50V; C_0805_2012Metric; MFR Part# CL21B103KBANNNC; LCSC C1710
C2: C_0402_1uF_25V; C_0402_1005Metric; MFR Part# CL05A105KA5NQNC; LCSC C52923
C3: C_0402_0.1uF_16V; C_0402_1005Metric; MFR Part# CL05B104KO5NNNC; LCSC C1525
D1: LED_0603_Red; LED_0603_1608Metric; MFR Part# KT-0603R; LCSC C2286
FB1, FB2: B_0805_600R; L_0805_2012Metric; MFR Part# GZ2012D601TF; LCSC C1017
H1, H2: GND; M1502-B-2545-AL-TOP
J1: Screw_Terminal_01x02_3.5mm_horiz; TerminalBlock_1x02_P3.50mm_Horizontal; MFR Part# KF350-3.5-2P; LCSC C474892
J2: Amphenol_91911-31321_plug; Amphenol_91911-31321LF_PLUG; LCSC C9900009023
R1: R_0402_10K; R_0402_1005Metric; MFR Part# 0402WGF1002TCE; LCSC C25744
U1: Thermal_MAX31855KASA; SOIC-8_3.9x4.9mm_P1.27mm; MFR Part# MAX31855KASA+T; LCSC C52028
U2: ICSL_LOGO; icsl_logo
U3: EEPROM_M24C02-WMN6TP; SOIC-8_3.9x4.9mm_P1.27mm; MFR Part# M24C02-WMN6TP; LCSC C7562

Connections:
/3V3: C2.1, C3.1, J2.19 (3V3), R1.1, U1.4 (VCC), U3.8 (VCC)
/5V: J2.21 (5V)
/A0: J2.16 (A0)
/A1: J2.17 (A1)
/CS: J2.9 (CE), U1.6 (~CS)
/MISO: J2.7 (MISO), U1.7 (SO)
/MOSI: J2.8 (MOSI)
/RXD: J2.13 (RX)
/SCK: J2.6 (SCK), U1.5 (SCK)
/SCL: J2.11 (SCL)
/SCL_EEPROM: J2.2 (SCL(E)), U3.6 (SCL)
/SDA: J2.10 (SDA)
/SDA_EEPROM: J2.1 (SDA(E)), U3.5 (SDA)
/Status: J2.15 (STAT)
/TXD: J2.14 (TX)
/~RST: J2.5 (~RST)
GND: C2.2, C3.2, D1.1 (K), H1.1, H2.1, J2.3 (GND), U1.1 (GND), U3.4 (VSS)
unnamed: C1.1, FB1.2, U1.3 (T+)
unnamed: C1.2, FB2.2, U1.2 (T-)
unnamed: D1.2 (A), R1.2
unnamed: FB1.1, J1.1
unnamed: FB2.1, J1.2

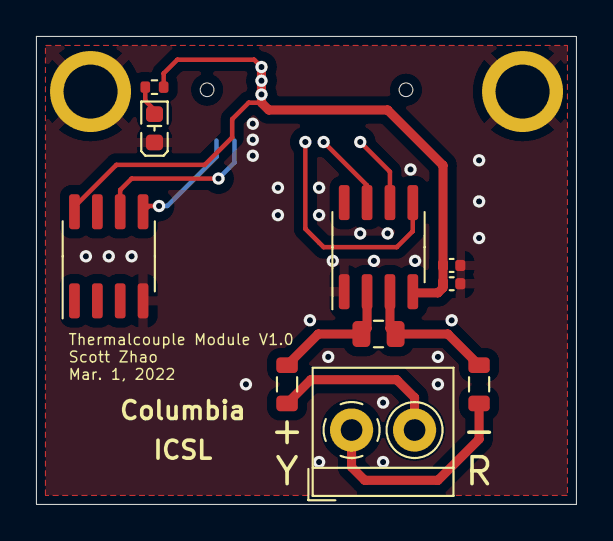
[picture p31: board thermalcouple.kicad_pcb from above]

Board: 4 copper layers, 30.0 x 26.0 mm, 14 parts (1 on the bottom side), 12 nets.

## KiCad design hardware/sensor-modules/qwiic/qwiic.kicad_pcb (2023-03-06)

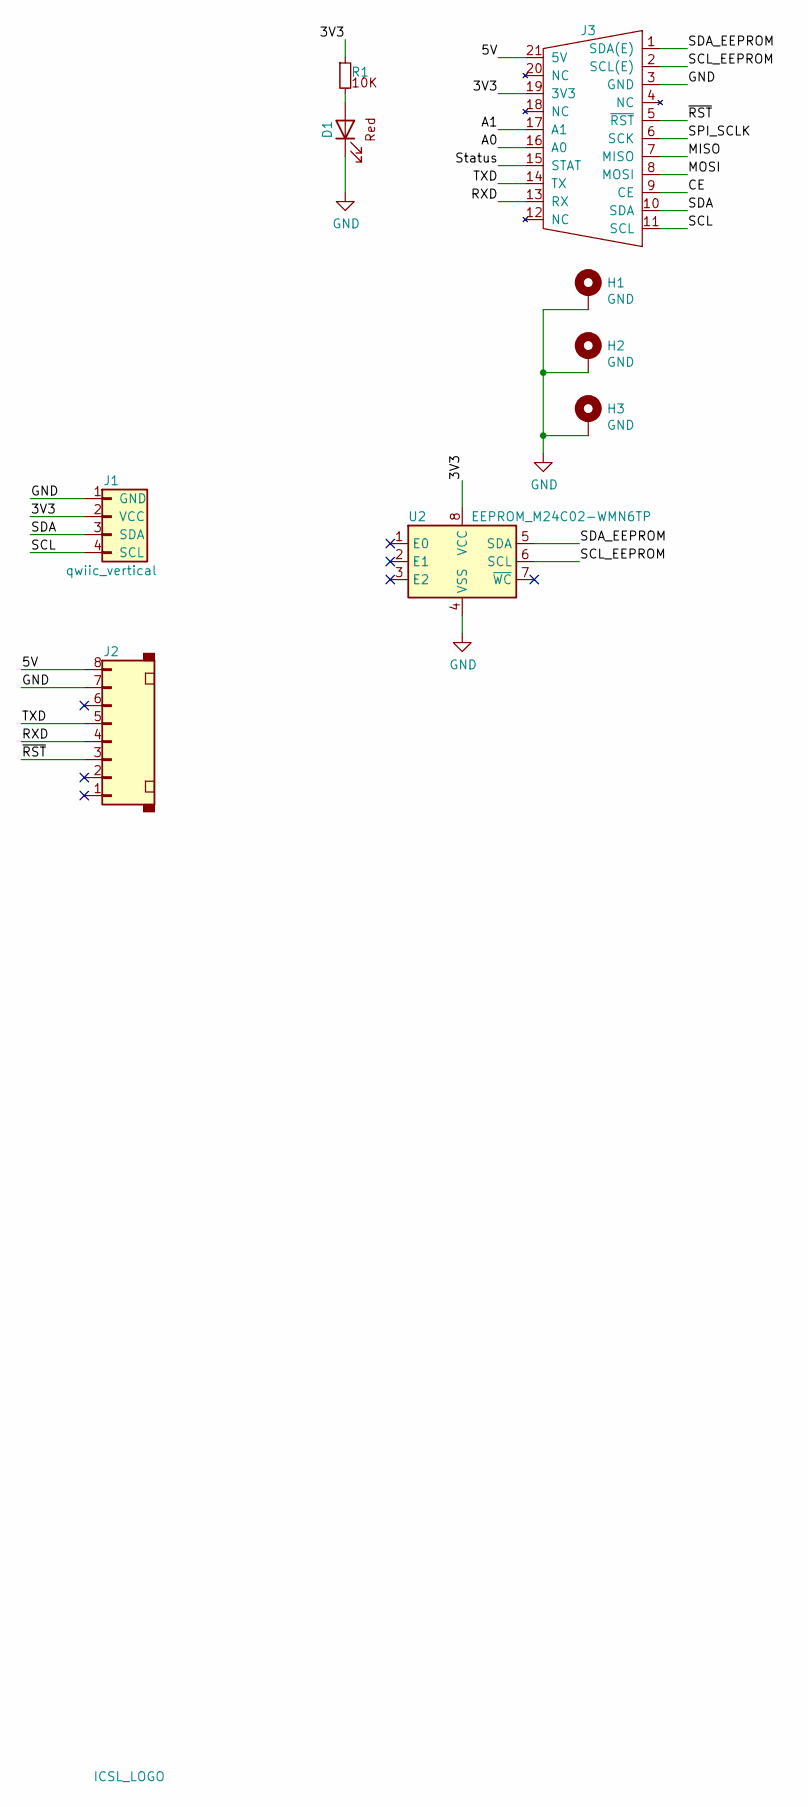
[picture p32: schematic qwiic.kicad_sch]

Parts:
D1: LED_0603_Red; LED_0603_1608Metric; MFR Part# KT-0603R; LCSC C2286
H1, H2, H3: GND; M1502-B-2545-AL-TOP
J1: qwiic_vertical; JST_SH_1x04_1.00mm_Vertical; MFR Part# C145961; LCSC C145961
J2: 1.25mm_8P_SMD_Vertical; Molex_PicoBlade_53398-0871_1x08-1MP_P1.25mm_Vertical; MFR Part# AFC12-S08CCC-00; LCSC C395349
J3: Amphenol_91911-31321_plug; Amphenol_91911-31321LF_PLUG; LCSC C9900009023
R1: R_0402_10K; R_0402_1005Metric; MFR Part# 0402WGF1002TCE; LCSC C25744
U1: ICSL_LOGO; icsl_logo
U2: EEPROM_M24C02-WMN6TP; SOIC-8_3.9x4.9mm_P1.27mm; MFR Part# M24C02-WMN6TP; LCSC C7562

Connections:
/3V3: J1.2 (VCC), J3.19 (3V3), R1.1, U2.8 (VCC)
/5V: J2.8, J3.21 (5V)
/A0: J3.16 (A0)
/A1: J3.17 (A1)
/CE: J3.9 (CE)
/MISO: J3.7 (MISO)
/MOSI: J3.8 (MOSI)
/RXD: J2.4, J3.13 (RX)
/SCL: J1.4 (SCL), J3.11 (SCL)
/SCL_EEPROM: J3.2 (SCL(E)), U2.6 (SCL)
/SDA: J1.3 (SDA), J3.10 (SDA)
/SDA_EEPROM: J3.1 (SDA(E)), U2.5 (SDA)
/SPI_SCLK: J3.6 (SCK)
/Status: J3.15 (STAT)
/TXD: J2.5, J3.14 (TX)
/~RST: J2.3, J3.5 (~RST)
GND: D1.1 (K), H1.1, H2.1, H3.1, J1.1 (GND), J2.7, J3.3 (GND), U2.4 (VSS)
unnamed: D1.2 (A), R1.2

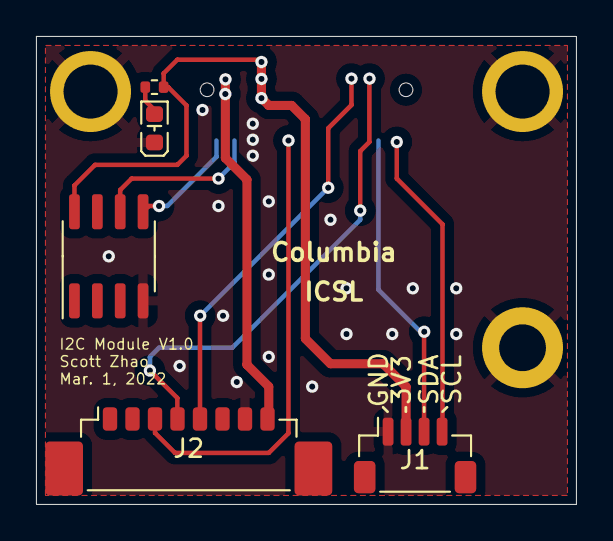
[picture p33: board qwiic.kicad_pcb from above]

Board: 4 copper layers, 30.0 x 26.0 mm, 10 parts (1 on the bottom side), 11 nets.

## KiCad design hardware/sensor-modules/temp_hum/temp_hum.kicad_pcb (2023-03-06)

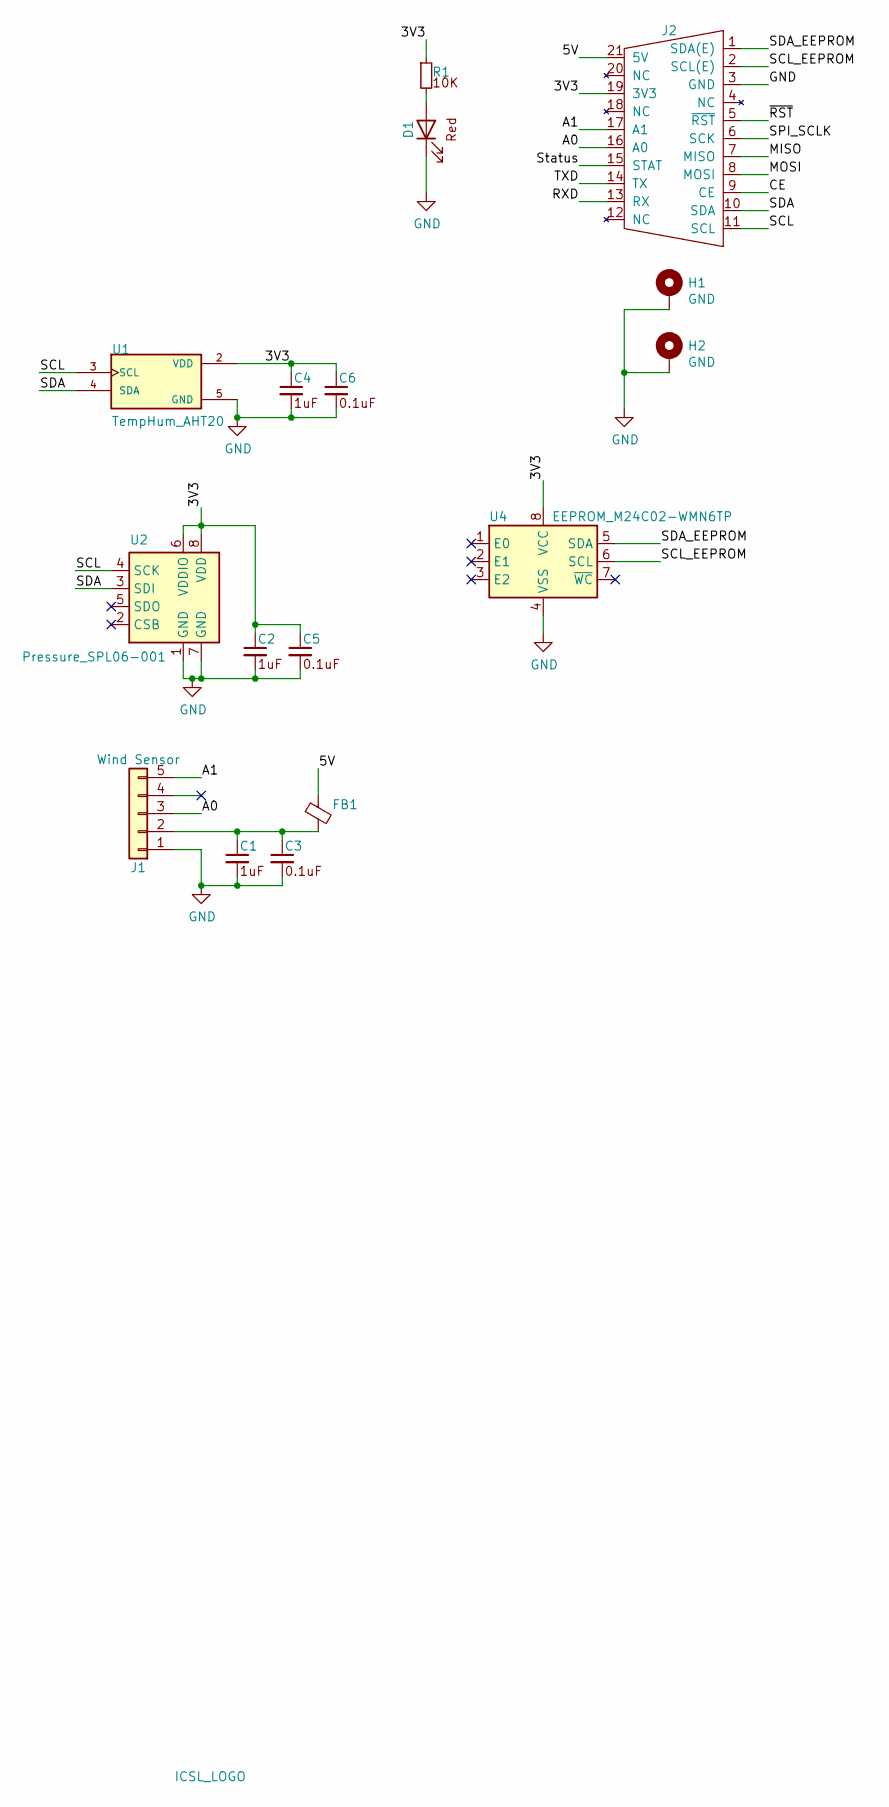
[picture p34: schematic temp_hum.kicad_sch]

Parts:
C1, C2, C4: C_0402_1uF_25V; C_0402_1005Metric; MFR Part# CL05A105KA5NQNC; LCSC C52923
C3, C5, C6: C_0402_0.1uF_16V; C_0402_1005Metric; MFR Part# CL05B104KO5NNNC; LCSC C1525
D1: LED_0603_Red; LED_0603_1608Metric; MFR Part# KT-0603R; LCSC C2286
FB1: B_0805_600R; L_0805_2012Metric; MFR Part# GZ2012D601TF; LCSC C1017
H1, H2: GND; M1502-B-2545-AL-TOP
J1: Wind Sensor; PinHeader_1x05_P2.54mm_Vertical
J2: Amphenol_91911-31321_plug; Amphenol_91911-31321LF_PLUG; LCSC C9900009023
R1: R_0402_10K; R_0402_1005Metric; MFR Part# 0402WGF1002TCE; LCSC C25744
U1: TempHum_AHT20; AHT20; MFR Part# AHT20; LCSC C2757850
U2: Pressure_SPL06-001; SPL06-001; MFR Part# SPL06-001; LCSC C2684428
U3: ICSL_LOGO; icsl_logo
U4: EEPROM_M24C02-WMN6TP; SOIC-8_3.9x4.9mm_P1.27mm; MFR Part# M24C02-WMN6TP; LCSC C7562

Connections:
/3V3: C2.1, C4.1, C5.1, C6.1, J2.19 (3V3), R1.1, U1.2 (VDD), U2.6 (VDDIO), U2.8 (VDD), U4.8 (VCC)
/5V: FB1.1, J2.21 (5V)
/A0: J1.3, J2.16 (A0)
/A1: J1.5, J2.17 (A1)
/CE: J2.9 (CE)
/MISO: J2.7 (MISO)
/MOSI: J2.8 (MOSI)
/RXD: J2.13 (RX)
/SCL: J2.11 (SCL), U1.3 (SCL), U2.4 (SCK)
/SCL_EEPROM: J2.2 (SCL(E)), U4.6 (SCL)
/SDA: J2.10 (SDA), U1.4 (SDA), U2.3 (SDI)
/SDA_EEPROM: J2.1 (SDA(E)), U4.5 (SDA)
/SPI_SCLK: J2.6 (SCK)
/Status: J2.15 (STAT)
/TXD: J2.14 (TX)
/~RST: J2.5 (~RST)
GND: C1.2, C2.2, C3.2, C4.2, C5.2, C6.2, D1.1 (K), H1.1, H2.1, J1.1, J2.3 (GND), U1.5 (GND), U2.1 (GND), U2.7 (GND), U4.4 (VSS)
unnamed: C1.1, C3.1, FB1.2, J1.2
unnamed: D1.2 (A), R1.2


Board: 4 copper layers, 30.0 x 26.0 mm, 17 parts (1 on the bottom side), 11 nets.

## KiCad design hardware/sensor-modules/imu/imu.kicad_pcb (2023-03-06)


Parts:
C1: C_0402_10nF_50V; C_0402_1005Metric; MFR Part# CL05B103KB5NNNC; LCSC C15195
C2: C_0402_1uF_25V; C_0402_1005Metric; MFR Part# CL05A105KA5NQNC; LCSC C52923
C3, C4: C_0402_0.1uF_16V; C_0402_1005Metric; MFR Part# CL05B104KO5NNNC; LCSC C1525
C5: C_0402_2.2nF_50V; C_0402_1005Metric; MFR Part# 0402B222K500NT; LCSC C1531
D1: LED_0603_Red; LED_0603_1608Metric; MFR Part# KT-0603R; LCSC C2286
H1, H2: GND; M1502-B-2545-AL-TOP
J1: Amphenol_91911-31321_plug; Amphenol_91911-31321LF_PLUG; LCSC C9900009023
R1: R_0402_DNP; R_0402_1005Metric
R2, R3: R_0402_10K; R_0402_1005Metric; MFR Part# 0402WGF1002TCE; LCSC C25744
U1: IMU_MPU-6050; InvenSense_QFN-24_4x4mm_P0.5mm; MFR Part# MPU-6050; LCSC C24112
U2: ICSL_LOGO; icsl_logo
U3: EEPROM_M24C02-WMN6TP; SOIC-8_3.9x4.9mm_P1.27mm; MFR Part# M24C02-WMN6TP; LCSC C7562

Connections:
/3V3: C1.1, C2.1, C3.1, J1.19 (3V3), R1.1, R3.1, U1.8 (VDDIO), U1.13 (VDD), U3.8 (VCC)
/5V: J1.21 (5V)
/A0: J1.16 (A0)
/A1: J1.17 (A1)
/CS: J1.9 (CE)
/MISO: J1.7 (MISO)
/MOSI: J1.8 (MOSI)
/RXD: J1.13 (RX)
/SCK: J1.6 (SCK)
/SCL: J1.11 (SCL), U1.23 (SCL)
/SCL_EEPROM: J1.2 (SCL(E)), U3.6 (SCL)
/SDA: J1.10 (SDA), U1.24 (SDA)
/SDA_EEPROM: J1.1 (SDA(E)), U3.5 (SDA)
/Status: J1.15 (STAT)
/TXD: J1.14 (TX)
/~RST: J1.5 (~RST)
GND: C1.2, C2.2, C3.2, C4.2, C5.2, D1.1 (K), H1.1, H2.1, J1.3 (GND), R2.2, U1.1 (CLKIN), U1.11 (FSYNC), U1.18 (GND), U1.25 (GND), U3.4 (VSS)
unnamed: C4.1, U1.10 (REGOUT)
unnamed: C5.1, U1.20 (CPOUT)
unnamed: D1.2 (A), R3.2
unnamed: R1.2, R2.1, U1.9 (AD0)


Board: 4 copper layers, 30.0 x 26.0 mm, 15 parts (1 on the bottom side), 10 nets.

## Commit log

2023-03-06 add module and dev PCB files
    [air_quality-CuBottom.gbr, air_quality-CuTop.gbr, air_quality-EdgeCuts.gbr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]
2023-03-06 add kicad library submodule
2023-03-06 cleanup dev board type 1
    [module_dev1-CuBottom.gbr, module_dev1-CuTop.gbr, module_dev1-EdgeCuts.gbr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]
2023-03-06 cleanup dev board type 2
    [module_dev2-CuBottom.gbr, module_dev2-CuTop.gbr, module_dev2-EdgeCuts.gbr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]
2023-03-07 cleanup dev board type 3
    [module_dev3-CuBottom.gbr, module_dev3-CuTop.gbr, module_dev3-EdgeCuts.gbr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]
2023-03-08 update hw readme; add template PCB
    [template-CuBottom.gbr, template-CuTop.gbr, template-EdgeCuts.gbr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]
2023-03-08 add template board screenshot
2023-03-08 add carrier board; update readme
    [ADC.kicad_sch, HeaderToRpi4_overlay1.kicad_sch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]
